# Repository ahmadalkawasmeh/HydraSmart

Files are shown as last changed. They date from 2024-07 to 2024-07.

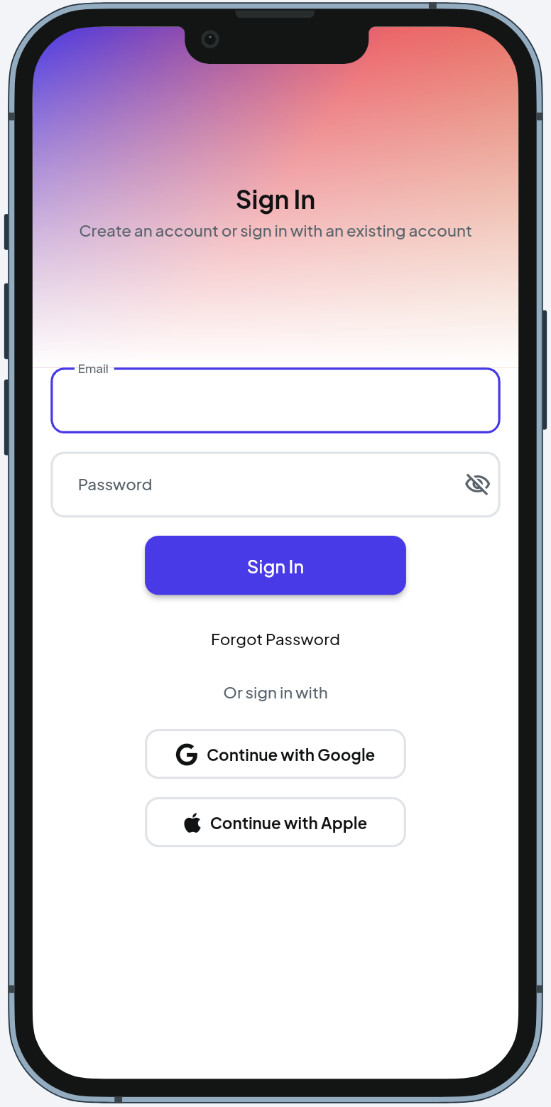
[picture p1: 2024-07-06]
application preview/loginPage.png

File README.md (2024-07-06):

## About
The focus of this project was to implement a portable and smart drinking water quality monitoring system,
in order to address the lack of availability of such product and the disadvantages of using conventional
paper test strips to measure water quality. The developed system consists of multiple sensors that infer
useful measurements about the water quality, conveniently built into a water bottle, as well as a mobile
application that provides an intuitive user interface for the user to interact with the system. This enabled
the users to be confident in the quality of water they intend to consume, without compromising
convenience or ease of use.

## Features
- Measures water quality in real time
- Sensors and other hardware components built into a water bottle for convenience
- Precisely calibrated and thoroughly tested for high accuracy
- Utilizes a rechargable battery for portability
- Simple and intuitive user interface design
- Compatible with both Android and IOS devices
- User data is encrypted and securely stored

## Key Documents
- [Final Report](https://github.com/ahmadalkawasmeh/HydraSmart/blob/main/documents/Final%20Report.pdf)
- [Application Screenshots](https://github.com/ahmadalkawasmeh/HydraSmart/tree/main/application%20preview)
- [Engineering Technical Drawings](https://github.com/ahmadalkawasmeh/HydraSmart/blob/main/documents/Engineering%20Technical%20Drawings.pdf)

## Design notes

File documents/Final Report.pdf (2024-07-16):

# ECOR 4907

# Capstone Project

# HydraSmart Final Report

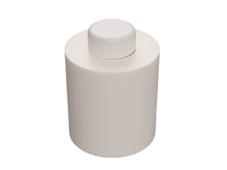
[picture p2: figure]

Prepared for:

Professor Safaa Bedawi

Professor Lynn Marshall

By:

Abdal Alkawasmeh, 1011987252

Ahmad Alkawasmeh, 101108706

July 10, 2024

FINAL REPORT

# Abstract

Have you ever thought about the cleanliness of your drinking water? Do you have to constantly drink

bottled water? Are you tired of second guessing if you should drink tap water? water quality has become

an emerging issue over the years and water quality systems have become more in demand.

In this project, we implement an automated water quality system which allow users to test the quality of

a water sample. Using a few metrics, the system provides the user with water quality readings and

determine the drinking water's safety by displaying a message to the user. By using this product, the user

will be able to carry and sample any water from anywhere.

This product ensures that the user consumes safe and drinking water and has many applications to its

users. However, it is most beneficial for those travelling or who do not have access to filtered water. For

example, teachers may wish to check the water quality on a field trip before the children start to consume

it.

# Acknowledgements

Special thanks to Professor Bedawi and Professor Marshall for their continued support and dedication. It

has been a pleasant and an amazing experience working with you. Although this project is coming to an

end, you have left us with an everlasting experience that reinforced professional practice and discipline

throughout the duration of the project. This has not only been instrumental to our success in this project

but will also be a major factor in our success throughout our careers.

We would also like to acknowledge Professor Dansereau and thank him for the valuable feedback he

provided us with.

Sincerely,

Ahmad and Abdal Alkawasmeh

## Table of Contents

## 1 Introduction

### 1.1 Background

We go about our everyday lives without giving much thought to the quality of water that we consume

daily. Especially as we need to consume a substantial amount of water daily, which is approximately 3.7

litres, to maintain healthy body functions. Thus, it is important to pay close attention to the quality of the

water we consume on a daily basis.

Currently, the most widely used technique of determining water quality is by using test strips, which are

rectangular pieces of paper that are saturated with a chemical agent, once these paper strips are

submerged in a water sample, the chemical agent will react with the water and change colour. This colour

indicates the test result, which then the user will need to match to a result chart in order to read the test

result. This method of testing the water quality is not accurate and cannot provide exact quantitative

results.

Another downside to using the test strips pertains to users with a visual impairment. Due to the inherent

nature of the test strips relying on a colour change to convey the test results, users with visual

impairments related to colour blindness may face difficulties using the test strips.

### 1.2 Motivation

The goal of this project was to develop a more suitable solution for monitoring the quality of drinking

water and to address the downsides of using traditional test strips.

For users with visual impairments, it can be challenging for them to discern fine differences in shades of

a certain colour. Which is the mechanism that test strips rely on to convey the test results to the user.

Thisinherently introduces a barrier for this group of users, and this method of evaluating the water quality

may even become unusable for them.

During our research into the existing solutions for monitoring drinking water quality, it became apparent

that there are currently no solutions for evaluating the quality of drinking water that are portable,

convenient, and simple to use by the end user. This creates a high demand for such a solution as it has a

wide range of applications and use cases.

For parents, it would put their minds at ease after becoming aware of the water quality their children will

consume, especially during times of uncertainty, such as when travelling or visiting a new city where they

are not sure of how that specific municipality treats their water.

For teachers, if they are accompanying children on a field trip, it would be immensely helpful to be able

to check the water quality before everyone consumes it. Moreover, if the water happens to be acidic or

contains contaminants, it will not provide the necessary hydration at the least, and in the worst-case

scenario it would cause everyone to get sick. Thus, a simple test prior to consumption would allow us to

mitigate any risks of consuming water that is of unknown quality or content.

### 1.3 Problem Statement

There are many drawbacks to using traditional test strips for assessing drinking water quality. The test

strips have a low accuracy for the test results asthe result is conveyed to the user through a colour change.

Aside from the lack of a quantitative test result, the colour change mechanism in itself can become

problematic for some users. Moreover, users with visual impairments may not be able to use the test

strips as they require acute colour perception to evaluate the test results. Additionally, there is a lack of a

suitable solution for assessing the quality of drinking water conveniently by the end users. Therefore, it is

essential to develop a product that addresses the disadvantages of traditional water quality testing

mechanisms and provides a solution to the public for evaluating the quality of drinking water

conveniently.

### 1.4 Proposed Solution

The solution proposed is a complete system (referred to as HydraSmart) for monitoring the quality of

drinking water. HydraSmart comprises multiple sensors conveniently built into a water bottle and a mobile

application that acts as an interface between the user and HydraSmart. This proposed solution is

convenient to use, portable, and provides highly accurate results. Thus, eliminating the disadvantages of

traditional mechanisms for evaluating the quality of drinking water, while simultaneously addressing the

lack of such a solution for the general public.

### 1.5 Overview Of Remainder of Report

This report describes the research, design and implementation process of the HydraSmart system. The

introduction introduces the team members, the objectives of this system, background and motivation,

problem statements and the proposed solution. This gives the reader a thorough understanding and

importance of the overall project.

The Engineering project discusses the health and safety concerns of the system, the professionalism,

describes the management process, the justification for choosing the project and the contributions of

each member. The Background section focuses on the background of the front end and backend, and the

hardware components. The requirements section describes the functional and non-functional

requirements of the system. The design section describes the design process of the front-end, back-end

and the physical water bottle design. The implementation sections describe the detailed implementation

process of the system, discussing the Figma mock-ups, the back-end implementation of the mobile app,

and the water bottle implementation of wiring, 3D-model and sensor integration. The theory and

techniques discuss the justification of the components in the system. Results and discussion show the

results of the system we were able to obtain and discuss future improvements.

## 2 The Engineering Project

### 2.1 Health and Safety

The system is designed to ensure the health and safety of the user in order to ensure a safe and positive

user experience. The design incorporates three hazardous components, electrical equipment, a

rechargeable battery, and glassware. These components are capable of causing bodily harm to the end

user if the product is mishandled or misused. However, health risks can be mitigated with appropriate

precautions and safety-centred design.

Due to the utilization of electronics and electrical components in this project, there is a risk of electrical

shock to the end user if the device is misused. Section 6.4 of the Health and Safety Guide outlines the

concept of guarding to prevent access to electrical components. Subsequently, the electrical connections

and components were placed in a waterproof compartment that is inaccessible to the user. Moreover,

the user will not be able to make contact with the wiring and electrical components of the system, thus

mitigating the risk of an electrical shock.

One of the system components will be a rechargeable battery pack, which was used to supply power to

the system and allow it to be mobile. The battery pack type is Lithium-Ion, which remains in a stable state

so long the battery casing is intact. If the casing becomes punctured or compromised at any time, the

battery may catch on fire. This would be catastrophic as it can cause severe burns to the user. As per

section 6.6 of the Health and Safety Guide, the use of Shielding is recommended for materials or chemicals

that may cause explosions and fires. As such, the strategy to mitigate this risk was to encase the battery

pack in metallic plates. This will reinforce the original plastic casing making it significantly harder to

penetrate.

Two sensor probes are made of glass and could pose a health risk if they break. As per section 6.7 of the

Health and Safety Guide, broken glassware should be handled and disposed of safely. Moreover, protective gloves and eyewear should be used when handling broken glass to minimize the risk of cuts. If

a sensor probe breaks, the recommended disposal method is to carefully place the broken glass in a

cardboard box, taping the box shut, labelling the box with "Broken Glass", and placing it next to the

garbage bin. This will minimize the risks and ensure it is handled safely by anyone that comes into contact

with it. Additionally, it is recommended to apply a thick layer of tape to the exterior of glassware to

prevent it from dispersing when broken. This was applied in the final product to minimize the health risks

to the end user.

### 2.2 Engineering Professionalism

One component of the 4th year engineering project is to demonstrate how our professional responsibilities

were met throughout the performance of the project. Previously, we completed a professional practice

course, ECOR 4995. Although it placed a strong emphasis on communication skills, it also taught us about

professional responsibilities, health and safety, and principles of sustainable development.

Throughout the duration of our project, we continuously utilized the concepts we were taught in

professional practice to communicate, amongst the team and with our supervisors, in an effective and

professional manner. To achieve this, we ensured our written communication is kept concise and

accurate.

Additionally, during our meetings and discussions, we made sure to always be punctual and be present

prior to the meeting time. This helps us conduct ourselves in a professional manner and demonstrates

that we highly value our supervisors’ time. However, on one occasion, we experienced unforeseen

circumstances that prevented us from attending the meeting on time. We immediately informed our

supervisors of this and provided an estimated arrival time, as it otherwise would be inappropriate.

The most notable component of professional practice that pertains to the goals of this project is

sustainable development. Sustainable development is concerned with preserving the environment and natural resources, in order to avoid impacting future generations' ability to make use of such resources.

HydraSmart will help reduce the amount of plastic waste resulting from disposable water bottles, thus

helping to preserve the environment from pollution and non-organic waste.

Another aspect of professional practice is health and safety and safeguarding the public. The concept of

public safeguarding pertains to making decisions that prioritize public safety. Throughout this project

development, public safety was considered the fundamental concept and main motivation. HydraSmart

will help upkeep the public safety and health by ensuring the water is fit for consumption, thus reducing

the chance of facing experiencing issues caused by drinking water that was not fit for consumption.

### 2.3 Project Management

We greatly benefited from creating a Gantt chart [Appendix C: Project Progression Gantt Chart] early on

to schedule and organize the execution of the project tasks throughout the duration of the project. This

helped us carry out the project objectives in an effective and efficient manner. Evidently, we employed

the principles of the Waterfall lifecycle model throughout the duration of this project, where we

incrementally completed each part before moving on to the next part. This ensured there are no broken

dependencies across the different parts of the projects, therefore increasing our efficiency.

We used JetBrains’ YouTrack in order to track our progress and identify any issues that must be resolved

in order to continue progressing through the project. YouTrack has a Gantt chart tool conveniently built

in, seamlessly enabling task allocation and progress tracking.

### 2.4 Justification of Suitability for Degree Program

The team members consist of Software Engineering students with a parallel experience in software

development, however, each member has a unique interest and background experience.

Ahmad employed his previous knowledge about software architecture and design from SYSC 4120 to

outline and analyze the system requirements. The knowledge acquired from COMP 3004 allowed him to

design the persistence layer of the mobile application. Utilizing Nielson’s Heuristics from SYSC 4130

enabled him to design an intuitive and user-friendly interface for the mobile application. His knowledge

in software verification and validation from SYSC 4101 assisted him in verifying correct sensor behavior.

The knowledge in design and analysis of automatic control systemsfrom SYSC 4505 allowed him to analyze

the sensor response characteristics. Additionally, the Introduction to Engineering (ECOR 1010) course

allowed him to acquire the necessary expertise in prototyping and 3D design, which was greatly utilized

in this project to design a custom water bottle housing.

Abdal’s interest is purely vested in software development. More precisely in user interface design and

identifying system requirements. He has taken on multiple personal projects in the past involving website

design and development, and he has an extensive experience in working with distributed database

systems. Some examples of related work include a sandwich ordering system web user interface which

was implemented in SYSC 3010. He has also used his knowledge in SYSC 4101 software verification and

validation to use various software testing strategies to verify that the sensors and IDE were operating

correctly. Also, the software architecture and design, SYSC 4120, helped him in identifying the functional

and non-functional requirements of the system.

Therefore, it is evident the expertise and experience required to complete this project has been greatly

reinforced by the undergraduate Software Engineering program. Thus, making this project a perfect fit for

Software Engineering students.

### 2.5 Individual Contributions

Please note that due to the limited number of team members in this project, each member contributed

to all the tasks outlined below and they are only categorized by each person based on the member that

contributed to completing more than 50% of the mentioned task.

2.5.1 Project contributions

Abdal | Ahmad
Software testing | Hardware component testing
Development of the mobile application | Development of the mobile application
Integration of pH, TDS and turbidity sensors | Integration of EC, and Temperature sensors
Calibration of sensors | Back-end Testing
Front-end Design | Back-end Design
Back-end Design | Interfacing portable battery power supply into the Raspberry Pi
Hardware Design | Hardware Design

Table 1: Breakdown of Project Contributions of Each Member

2.5.2 Report contributions
Abdal | Ahmad
Chapter 2: Engineering Design | Chapter 1: Introduction
Chapter 5: Hardware Required | Chapter 3: Work Plan
Chapter 6: References | Chapter 4: Project Risks and Mitigation Strategies
| Appendences

Table 2: Breakdown of Proposal Contributions of Each Member

Abdal | Ahmad
Abstract | Chapter 2: Professional considerations
Chapter 1: Introduction | Chapters 3.2 and 3.3: Design Functionality Verification, Experiment Design and Setup
Chapter 2.1: Health and safety | Chapter 4: Results and Discussions
Chapters 3.1 and 3.4: Generation of Alternative Design and Assessments, Hardware and Software Tools | Chapter 5: Conclusion

Table 3: Breakdown of Progress Report Contributions of Each Member

Abdal | Ahmad
1: Introduction | 2.0: The Engineering Report
2.4: Justification of Suitability for Degree Program | 3.1.1: FlutterFlow 3.1.2: Firebase
3.1.3: Background: Fusion 360 3.1.4: Background: Arduino IDE 3.2: Hardware | 5.1: Frontend Design 5.2: Backend Design
4: Requirements | 7.1: Frontend Implementation 7.2.1: Firebase-Application Line 7.2.2: Firebase Data Query and Update 7.2.3: Data Processing
5.3: Hardware Design | 8.2: Hardware Testing
6.1-6.6: Alternative Solutions Analysis | 9.0: Project Milestones
7.2.4-7.2.6: Hardware Implementation | 10.0: Conclusions
8.1: Software Testing | References and Appendences

Table 4: Breakdown of Final Report Contributions of Each Member

## 3 Background

### 3.1 Software

3.1.1 FlutterFlow

FlutterFlow was chosen for our mobile application development platform, see Chapter 6 for the trade-off

analysis of all our technologies and tools discussions.

FlutterFlow is a complete application development platform which houses all the necessary tools to

develop a mobile application from the ground up. It utilizes the Flutter Software Development Kit (SDK)

framework alongside the Dart programming language to develop high-quality mobile applications.

The Flutter SDK is universally compatible with Android and IOS devices, as well as multiple programming

languages such as Java, C, and Swift. This provides ultimate flexibility enabling application deployment to

multiple operating systems simultaneously.

Dart is a modern object-oriented programming language created by Google. This makes it seamless to

integrate other solutions created by Google into the mobile application, such as the Firebase data

persistence solution by Google. An added advantage of using FlutterFlow, is the ability to compile the Dart

application into JavaScript, enabling live testing and editing in a browser window.

While the graphical interface of the mobile application is developed using Dart and Flutter, it is formatted

in eXtensible Markup Language (XML), which is a popular format amongst graphical user interface

developers. It is known for its flexibility and universal compatibility with a wide range of operating systems

and programming languages.

Additionally, FlutterFlow makes it possible to develop for both Android and IOS devices simultaneously.

This is enabled through the Flutter Software Development Kit (SDK).

3.1.2 Firebase

To synchronize and store the sensor measurements, we used Firebase. Which is a data storage solution

created by Google. Similarly to Dart, Google provides exceptional and seamless integration between its

products. This made Firebase the clear choice when deciding on a database solution.

Firebase is a real-time database, meaning data updates are reflected immediately within the database.

This is a highly valued feature in applications that rely on live data to achieve a specific functionality. In

our project, it is imperative that the mobile application is able to retrieve live data from the sensors to the

user.

3.1.3 Arduino IDE

The main IDE we used to integrate the sensors into the system was Arduino. Arduino is a software

application built on C++. It provides users with a user-friendly interface that is easy to navigate and

develop code with. It also comes with many built in libraries allowing for advanced functionalities such as

sensor readings. It is also important to note the open-source feature, meaning that users can modify code

according to their needs or their specific application.

3.1.4 Fusion 360

To Design the 3-D model of the water bottle, we used fusion 360, a 3-D computer aided design program

created by Autodesk. This software is well known for its affordability, flexibility and many use of

applications. It’s also compatible with many operating systems such as MacOS, windows, and Sonoma.

It also has many functionalities such as generative design, rendering, and simulation. The generative

design uses an existing model structure and improves it by reducing the materials while attempting to

improve shear and normal resistance. This software is also equipped with fast rendering abilities allowing

the visualization of any 3D models. Fusion also uses finite element analysis which evaluates the mechanical properties of an object. This feature is quite critical in decision making between different

material manufacturing types, ensuring the best durability of the designed product [1]

### 3.2 Hardware

3.2.1 Temperature Sensor

The temperature sensor was a crucial part of our system. It helps provide accurate measurements of

other sensors as temperature is part of the formula used to calculate the readings. For example, when

temperature increases in a solution, the equilibrium is forced to lower the temperature by absorbing

more heat. This results in more formation of H+ ions and therefore a lower pH of a solution [2]

Similarly, with electrical conductivity, as the temperature of the water increases, the electrical

conductivity also increases. At higher temperatures, water molecules move more quickly, carrying more

charged ions. Therefore, this increases the overall conductivity [3].

3.2.2 EC Sensor

The electrical conductivity sensor determines the concentration of ions/dissolved substances in a

solution, where high conductivity usually means a higher amount of salts present in the solution and

vice versa [4]

This measurement is used in many applications such as cooling towers and wastewater management,

and each measurement in an application could mean various things. Even small amounts of salts can

result in high conductivity. It’s also possible that the water could be polluted or an existence of a sewage

leak. An EC sensor is made up of two surfaces, platinum and graphite, and a voltage waveform is sent

from one surface to the other, providing an EC reading [5]

3.2.3 pH Sensor

The pH sensor is used to determine the alkalinity of water in our system, a very important measure in

water quality. This measurement is used in a wide variety of applications such as swimming pools and

aquaculture. It’s important to understand that a pH value that is too low or too high could determine

the presence of heavy metals, or other toxic materials [6]. Most fish and aquatic animals have a pH

threshold of 6.5-9, so most aquatic systems add buffers to prevent pH fluctuations. In swimming pools,

pH of water is usually kept at 7.2-7.8, and if a pH rises too much, this can result in growth of algae and

bacteria. Drinking water should have a pH of 6.5-8.5 for safe human consumption. When the pH is too

acidic, it can damage pipes and can cause metal built up. When the pH is too basic, it can cause a change

in taste of water [8].

3.2.4 Turbidity Sensor

A Turbidity sensor measures the transparency or clearness of water. A high level of turbidity can indicate

sediments or pollutants in water [9]. This measurement is very commonly used in water treatment to

determine if water has been treated successfully [10] Turbidity is measured in NTU or FTU, where in

developed countries drinking water should be kept under 1 NTU and 5 NTU in developing countries. It’s

also helpful in determining the number of pollutants in water in the case of financial and technical

limitations [11].

A Turbidity sensor measures the transparency or clearness of water. A high level of turbidity can indicate

sediments or pollutants in water [9]. This measurement is very commonly used in water treatment to

determine if water has been treated successfully [10] Turbidity is measured in NTU or FTU, where in

developed countries drinking water should be kept under 1 NTU and 5 NTU in developing countries. It’s

also helpful in determining the number of pollutants in water in the case of financial and technical

limitations [11].

3.2.5 TDS Sensor

A TDS sensor measures the total dissolved solids, more specifically, the amount of minerals in water.

There are many sources of dissolved solids such as minerals, agritictural runoff and industrial pollution.

While some dissolved solids are beneficial, high TDS values can be harmful. Minerals such as calcium and

magnesium are usually present in water and are beneficial for human health. However, high levels of

TDS can cause health problems those with certain conditions such as high blood pressure, or kidney

disease. TDS is calculated by measuring the electrical conductivity of water and converting it to a TDS

reading. The amount of conductivity indicates the number of ions in the water, therefore providing a

TDS reading. The unit of measurement used to measure the TDS of a solution is ppm (parts per million),

indicates the concertation of one part in a million. The world health organization (WHO) recommends a

TDS level of less than 500 ppm for drinking water, but this can vary depending on the source and desired

use. For an example water used for plants can have a higher TDS [12].

A TDS sensor measures the total dissolved solids, more specifically, the amount of minerals in water. There

are many sources of dissolved solids such as minerals, agritictural runoff and industrial pollution. While

some dissolved solids are beneficial, high TDS values can be harmful. Minerals such as calcium and

magnesium are usually present in water and are beneficial for human health. However, high levels of TDS

can cause health problems those with certain conditions such as high blood pressure, or kidney disease.

TDS is calculated by measuring the electrical conductivity of water and converting it to a TDS reading. The

amount of conductivity indicates the number of ions in the water, therefore providing a TDS reading. The

unit of measurement used to measure the TDS of a solution is ppm (parts per million), indicates the

concertation of one part in a million. The world health organization (WHO) recommends a TDS level of

less than 500 ppm for drinking water, but this can vary depending on the source and desired use. For an

example water used for plants can have a higher TDS [12].

3.2.6 Arduino Uno R4 Microprocessor

An Arduino Uno R4 Wi-Fi is a microcontroller used to integrate the sensors, and other hardware. It

combines the processing power of the RA4M1 microcontroller from Renesas with the wireless

connectivity power of the ESP32-S3 from Espressif. The UNO R4 Wi-Fi has an expanded memory of 32 kB

and clock speed of 48 MHz, enabling precises calculations [13].The 12-bit Digital to analog converter

provides simplicity, and compatibility to most hardware. This microcontroller is also equipped with Wi-Fi

and Bluetooth built in the ESP32-D3 module, enabling users to connect wirelessly. In addition, this board

is equipped with a 24 V tolerance allowing for more hardware integration using a single power source. As

an error detection mechanism, this board is able to detect runtime errors and provides detailed

explanations about the error [14].An Arduino Uno R4 Wi-Fi is a microcontroller used to integrate the

sensors, and other hardware. It combines the processing power of the RA4M1 microcontroller from

Renesas with the wireless connectivity power of the ESP32-S3 from Espressif. The UNO R4 Wi-Fi has an

expanded memory of 32 kB and clock speed of 48 MHz, enabling precises calculations [13].The 12-bit

Digital to analog converter provides simplicity, and compatibility to most hardware. This microcontroller

is also equipped with Wi-Fi and Bluetooth built in the ESP32-D3 module, enabling users to connect

wirelessly. In addition, this board is equipped with a 24 V tolerance allowing for more hardware

integration using a single power source. As an error detection mechanism, this board is able to detect

runtime errors and provides detailed explanations about the error [14].

## 4 Requirements

Our system has two main components, the mobile application and the hardware. The mobile application

serves as a user interface while the hardware is responsible for the functionality of the sensors. Therefore,

by combining the two components, we developed a portable drinking water quality monitoring system,

ensuring the ease of use and convenience.

The system requirements are portioned into functional and non-functional requirements. The functional

requirements specify and describe the behaviour of the system, while the non-functional requirements

specify how the system should perform.

Functional requirements:

- The system shall be able to measure the pH level of the water with an accuracy of ± 0.1 in a range

of 0-14.

- The system shall be able to measure the amount of Total Dissolved Solids (TDS) in the water with

an accuracy of ±10 ppm within a range of 0-1000 ppm.

- The system shall be able to measure the amount of Total Suspended Solids (TSS or Turbidity) in

the water with an accuracy of ±10 NTU within a range of 0-1000 NTU

- The system shall be able to measure the Electrical Conductivity (EC) of the water with an accuracy

of ±100 µS/cm within a range of 0-10,000 µS/cm

- The system shall be able to measure the Temperature of the water with an accuracy of ±1 °C

within a range of 0-100 °C.

- The system shall have a graphical user interface which displays the readings of pH, TDS, TSS, EC.

Non-functional requirements:

- The user interface shall be friendly and intuitive to use.

- The system shall be compatible with both iOS and Android devices.
- The system hardware component shall be placed in waterproof and drop proof enclosure.
- The system shall support only 2.4 GHz Wi-Fi connection for maximum compatibility.
- The mobile application shall allow users to sign in using multiple methods for convenience.
- The system shall ensure the data is stored safely by preventing an unauthorized party from

accessing the data.

- The system shall prompt the users to sign in before allowing them to navigate the mobile

application.

- The mobile application shall update the displayed data within 10 seconds of being fetched.

## 5 Design

### 5.1 Frontend Design

The frontend design started by creating preliminary user interface mock-upsin Figma. During this process,

the goal was to design the mobile application pages in a simplified and high-level fashion. By creating the

mock-ups, it streamlined the implementation later in Flutter.

We designed a set of pages for the mobile application user interface. These pages [Appendix A: Mobile

Application Screens] were designed as follows:

- Welcome page: a landing page that appears upon launching the application to welcome the user

and it contains a single button to proceed

- Login page: the page where a user can create an account or sign in
- Home page: provides an overview of the recent measurements plotted on a graph. It also contains

two buttons named “Settings” and “Analytics Dashboard”

- Settings page: this is where the user can view and edit their profile, log out, and switch between

a dark and a light interface. It also contains a go-back button to navigate back to the home screen.

- Analytics dashboard page: this page displays a summary about the sensor measurements, and it

refreshes every 2 minutes automatically. It displays a button named “Measure” the user can press

and take an immediate measurement manually. Additionally, pressing on any of the sensor names

will navigate to a page that is dedicated to that specific sensor. In the upper left corner, there is a

“go-back” button to navigate back to the home screen.

- pH, EC, TDS, and Turbidity pages: each of these pages contain the same elements, the sensor

measurement and its units, a short explanation of what the measurement entails, ideal

measurement value, and a “go-back” button to navigate back to the dashboard page.

- E. coli page: this page displays the levels of E. coli bacteria present in the water of the beaches

and rivers in Ottawa, which are provided daily by the City of Ottawa.

Additionally, we utilized the principles of usability we learned about in our Human-Computer Interaction

course we completed previously. These principles, such as Nielsen’s Heuristics, can be used as a general

guideline during the design of user interfaces to increase usability, make the interface more intuitive to

use, and minimize issues users may face while using the application.

The first principle we applied is referred to as “Recognition Rather than Recall”. This principle is the most

widely applied across user interfaces. It is concerned with minimizing user memory load by enabling them

to recognize an action they need to perform in order to complete a certain task. For example, in

smartphones, the gear icon on the home screen allows the user to recognize that it refers to the Settings

page without having to recall that. This introduces a sense of familiarity within the interface and allows

the user to navigate it seamlessly.

In our case, there is two buttons on the home screen of the mobile application, “Settings” and “Analytics

Dashboard”. We used a gear icon for the “Settings” button, and a trendline icon for the “Analytics

Dashboard” button.

The second principle we applied is referred to as “User Control and Freedom”. This principle is concerned

with providing the user with complete freedom in navigating the interface as they please. Additionally, it

includes the ability to go back or undo an action the user performed previously. This makes the user more

comfortable with navigating the interface and be confident to explore the interface without hesitation.

Throughout the application pages, we ensured to include a go-back button on every page, providing

complete freedom to the user in navigating the application pages. We also used a left-arrow icon for this

button, repeatedly applying the “Recognition Rather than Recall” principle.

The third principle we applied is referred to as “Aesthetic and Minimalist Design”. This principle is about

excluding irrelevant and rarely used information from being displayed on an interface. Otherwise, the

extra information displayed on an interface competes with the relevant information and diminishes their

relative visibility. Throughout the application interface, we ensured that each page displays only the

essential information only. For example, the dashboard page displays ratings of sensor measurements

initially, and instructs the user to press on a sensor name to view more information about it. Once the

user presses on a sensor name, a secondary page is shown, and it displays detailed information dedicated

to that sensor.

This is also related to Fitt’s Law predictive model, which states that the time to point to an object is a

function of the distance from target object and the size of that object. In other words, the user will be

able to point to a larger sized object faster than a smaller sized object. Moreover, the more elements

displayed on an interface page, the less attention the user is going to assign to each of these elements.

Therefore, it is more preferrable to partition information and elements amongst multiple pages rather

than having one large page, effectively enabling the user to pay adequate attention to each page or set of

elements.

### 5.2 Backend Design

We started the backend design process by designing a Firebase database schema to account for the data

and measurements we need to persist throughout the system. The database needed to include four

tables.

The first table, named “users”, was needed to store the profile information of the users. Including user id,

photo, name, and email. This information is needed by the application in order to create a new user and

authorize them to use the application.

The second table, named “sensorData”, was needed for storing and retrieving sensor measurements. It

contains 4 rows that store the measurements of the pH, Electrical Conductivity, Turbidity, and Total

Dissolved Solids sensors.

The third table, named “liveMeasure”, was needed to facilitate the communication between the mobile

application and the Arduino microprocessor. It contains one row that stores a single integer, either a 1 or

0.

The fourth table, named “eColi”, was needed to relay the current levels of E. coli bacteria present in

beaches and rivers in Ottawa, and whether there has been rainfall in the past 24 hours. The table contains

4 rows that store the E. coli levels, and one row that stores the rainfall status for the previous 24 hours.

Additionally, we wanted to ensure that the database and the stored data is kept safe. There are two critical

categories of data that are of concern. The first is the Firebase API access key, which is used to update and

query data from the database, is stored by the mobile application and the Arduino microprocessor. This

key was encrypted using SHA-256 and can only be decrypted by the mobile application and the Arduino

at runtime. The second critical data category was the actual data stored within the Firebase tables, this

data was encrypted using SHA-1 and similarly to the API access key, it can only be decrypted at runtime.

The sensors are controlled using two Arduino scripts. The first script contains several libraries to function

the sensors. Another script was included to contain the credentials of the firebase project and Wi-Fi

network. Once the sensor script is run, it automatically connects to the specified network and all sensor

data is printed in the serial monitor. This data is also sent to the firebase in real-time which is then shown

in the mobile application.

### 5.3 Hardware Design

The physical design of the water bottle is designed using fusion 360, which consists of three main

components, the inner cylinder, the outer cylinder and grommet seals. The inner cylinder’s purpose is to

fit the sensors. The outer cylinder’s purpose is a platform to hold the sensors. The grommets are to ensure

proper fitment of each sensor. To ensure the measurements was accurate, we carefully and iteratively

measured each sensor’s dimensions using calipers. Then, different mounts were designed for each sensor

on the bottom of the water bottle ensuring stability of the sensors and accessibility to water. We also took

into consideration the dimensions of the breadboard, rechargeable battery and the Arduino board as they

are required to power the sensors. The turbidity sensor is short in length, and therefore was placed on

the lowermost front position on the inner cylinder. A complete list of the hardware components we used

can be found in [Appendix D: List of Hardware Components Used]. Additionally, the detailed datasheet

for each component can be found in [Appendix E: Hardware Components Datasheets].

## 6 Generation and Analysis of Alternative Solutions

### 6.1 Microprocessor

When choosing a microprocessor for the system, we considered two options: the Arduino uno and the

Raspberry Pi. The Arduino Uno supports both analog and digital inputs, making it compatible with various

sensors. It’s simpler to program, ideal for development. Additionally, it is more energy efficient making it

suitable applications equipped with batteries. However, the Arduino Uno lacks an operating system, which

limits the potential of complex projects, and is more suitable for simpler ones [15].

The Raspberry Pi offers compatibility for digital input and runs a full operating system, providing complex

abilities and software support. It’s better suited for projects requiring more complexity. However, this

option is more expensive, lacks compatibility for analog input and consumes more power.

Due to our system requirements, the Arduino was found to be more feasible. Our sensors requiring both

analog and digital inputs, and the Arduino’s lower power consumption played important factors in this

decision. Although the Raspberry Pi offered more flexibility, it’s higher cost and power usage made it less

suitable for our needs [16].

Microprocessor/microcontroller | Advantages | Disadvantages
Arduino Uno R4 Wi-fi | • Includes analog and digital pins • Simple and easy to use • Low power consumption | • Does not use an operating system • Suitable for only small applications • 8-bit CPU architecture
Raspberry Pi | • Has 40 digital pins | • Does not support analog input

- Suitable for large and

complex applications

- Runs on an operating

system

- More expensive
- | High | power
| consumption

Table 5: Trade-off Analysis of Microprocessor/Microcontroller

### 6.2 Temperature sensor

When choosing a temperature sensor, there were several options available. However, the two most

competitive were the DFRobot DS18B20 and DFRobot TMP100. The DS18B20 model has it’s benefits like

being waterproof, smaller in size, and a more affordable option. However, it has a slightly less accuracy,

measures up to 125 and takes a few minutes to stabilize [17] [18]. The TMP100 model, on the other hand,

offers higher accuracy, stabilizes very quickly, and is compatible with both 5V and 3.3V systems, including

the Arduino DUO and UNO models. Given our goal to keep costs low, and the need to measure

temperatures of water solutions, we chose the DS18B20 model [19] [20].

Sensor | Advantages | Disadvantages
DFRobot DS18B20 | • Waterproof • Compact size • Affordable | • Less accurate • Measures temperature only up to 125 • Takes time to stabilize
DFRobot TMP100 | • High accuracy • Quick stabilization • Compatible with 5V and 3.3V | • Not waterproof • More expensive • Requires soldering

Table 6: Trade-off Analysis of Temperature Sensor

### 6.3 pH sensor

To choose the optimal pH sensor, we evaluated two popular options: the DFRobot model and the Grove

model. The DFRobot model can measure a wider temperature range, from 0 to 60, while the Grove

model is limited to 55. Additionally, the DFRobot model has a faster response rate of 1 minute and

includes a power LED indicator [21].

The Grove model offers several benefits, such as a smaller probe size, higher accuracy rate, and the

convenience of requiring calibration only once [22] . However, it has a slower response rate of more

than a minute, shorter probe life of 6 months and a longer cable length, which is not optimal for

minimizing materials [23] [24]

Despite the Grove model’s higher accuracy and smaller probe size, the DFRobot offers a wide temerpature

range, and a faster response rate. Therefore, given our needs and requirements, the DFRobot pH meter

was found more suitable.

Sensor | Advantages | Disadvantages
DFRobot pH meter | • Measures a wider temperature range • Faster response time • Includes power LED indicator | • Less accurate • Larger probe size • Requires frequent calibration
Grove pH sensor | • Smaller probe size • Higher accuracy • Only requires one-time calibration | • Slower response time • Shorter probe lifespan • Longer cable length

Table 7: Trade-off Analysis of pH Sensor

### 6.4 TDS sensor

When deciding on the TDS sensor, we compared two competitive products: the DFRobot Gravity TDS

sensor and Grove TDS sensor. The DFRobot sensor has a lower error rate, is waterproof, and can operate

with both 3.3V and 5V of power. However, it has a larger wire size, is only compatible with Arduino and

requires frequent recalibration [25]. In contrast, the Grove sensor has a shorter wire length, does not

require recalibration and is compatible with both Raspberry Pi and Arduino, however it has its limitations

such as not being useable in polluted water, not functioning in temperatures over 70, and lacking

waterproof capabilities [26].

Given our comparison, the DFRobot Gravity TDS sensor was found to be more suitable for our system.

Despite it’s larger wire size and need for frequent calibration, it’s waterproof capabilities and lower error

rate makes it the more optimal choice for our needs.

Sensor | Advantages | Disadvantages
DFRobot Gravity TDS analog sensor | • High accuracy • Waterproof probe • Compatible with 3.3V and 5V | • Longer wire size • Not compatible with Raspberry pi • Requires frequent calibration
Grove TDS sensor | • Shorter wire size • No recalibration required • Compatible with the Raspberry Pi and Arduino | • Not suitable for water temperatures over 70 • Cannot be used in polluted water • Non-waterproof probe

Table 8: Trade-off Analysis of TDS sensor

### 6.5 Turbidity sensor

When choosing a turbidity sensor, we considered two options: the DFRobot and the Grove sensor. The

DFRobot model is lighter in weight, more affordable, and has the ability to adjust the threshold. However,

it has its limitations, such as only being compatible with the Arduino, a slower response rate and requiring

calibration [27]. The Grove sensor is more beneficial in terms of power consumption, size, and output

support. However, it is more expensive, slightly heavier, and requires calibration [28].

Despite the slower response time, and requiring calibration, the DFRobot model offers significant

advantage in cost and weight. Therefore, based on our analysis, it was found to be a more practical option

for our project.

Sensor | Advantages | Disadvantages
DFRobot Gravity Turbidity sensor | • Lighter weight • More affordable • Adjustable threshold | • Only compatible with Arduino • Slower response time • Requires calibration
Grove Turbidity sensor | • Less power consumption • Smaller size • Supports both digital and analog output | • More expensive • Slightly heavier • Requires calibration

Table 9: Trade-off Analysis of Turbidity Sensor

### 6.6 EC sensor

When evaluating the DFRobot Gravity EC sensor and the Grove EC sensor, several factors were considered

including probe life, temperature range, compatibility, cost, and power consumption.

The DFRobot Gravity EC sensor offers a longer probe life, making it suitable for extended use and is also

more cost-effective. Also, it has a greater EC detection range which provides more application flexibility.

However, it has it’s limitations such as operating in a smaller temperature range, and consumes more

power [29]. The Grove EC sensor has the ability to operate in a larger temperature range, providing more

flexibility. It’s also compatible with both the Arduino and Raspberry Pi. Additionally, it consumes less

power. However, some limitations include a higher cost, a shorter probe life, and a low electrical

conductivity detection range [30].

Since cost and an EC detection range are very important to this project, and we are exclusively working

with the Arduino, the DFRobot is a more suitable choice.

Sensor | Advantages | Disadvantages
DFRobot Gravity EC sensor | • Longer probe life • Cost-effective • Greater EC detection range | • Narrower temperature range • Only compatible with Arduino • Higher power consumption
Grove EC sensor | • Wider temperature range • Compatible with Arduino and Raspberry Pi • Lower power consumption | • More expensive • Shorter probe life • Lower EC detection range

Table 10: Trade-off Analysis of EC Sensor

### 6.7 Software

6.7.1 Mobile Application Platform
For choosing a mobile application development platform, Flutter and React Native were evaluated on

several factors such as performance, useability, and suitability.

Flutter has the ability to use a single across multiple platforms such as iOS and Android, ensuring

portability. It’s drag and drop widgets allows for a highly responsive user interface, while direct

compilation to native ARM provides excellent performance. However, Flutter faces limitations like larger

application size, and a smaller library ecosystem and community support due to its recent invention.

React Native utilizes JavaScript, a widely used language with many libraries and tools. It also uses native

components (UI) to create the app’s user interface, providing a smoother and quicker performance. React

native applications usually require a lower minimum SDK version, making it lighter. However, it’s

dependency on native modules can impact performance and Its development process as it requires

knowledge of react and native UI components. Additionally, it may experience occasional UI

inconsistences [30]

In conclusion, Flutter’s various features, including the drag and drop capabilities and excellent

performance, make it a better platform for efficient mobile application development.

Mobile Application Platform | Advantages | Disadvantages
Flutter | • Single codebase for iOS and Android • Drag and drop widgets • Direct compilation to native ARM | Larger application size Smaller library ecosystem Limited community support
React | • Uses native component, resulting in a smoother performance • Requires minimal SDK • Extensive libraries and tools | • Dependency on native modules, affecting the performance • Requires knowledge of react • UI inconsistencies

Table 11: Trade-off Analysis Software Development Platform

6.7.2 IDE
For choosing an IDE, Arduino and Thonny, an IDE used in Raspberry Pi were evaluated on several factors

such as compatibility and portability. The Arduino IDE supports multiple platforms such as MacOS,

Windows and Linux, and offers useful features such as automatic board detection and autosave when

compiling. However, it can be somewhat difficult to navigate, especially for a beginner and lacks

debugging capabilities [31] [32].

Thonny, in comparison offers a more beginner friendly environment with a built-in python interpreter and

step by step debugging. However, it also ha limitations such as the lack of autosave when compiling, and

limited extensibility [33].

In conclusion, the several features of Arduino such the support of multiple platforms and autosave

compiler make it more suitable.

IDE | Advantages | Disadvantages
Arduino | • Support multiple platforms • Automatic board detection • Autosave when compiling | • A bit complex to navigate • Lacks debug capability • Lacks advanced features
Thonny | • Easy to navigate for beginners • Built in python interpreter • Step by step debugging | • Requires saving when compiling • Limited features • Not extensible as other IDEs

Table 12: Trade-off Analysis of IDE

6.7.3 Database
When comparing Firebase and MySQL, there are several differences to note. Firebase offers a NoSQL

database, real-time data synchronization, and a serverless architecture. However, Firebase faces several

limitations such as limited support for server-side architecture, vendor Lock-ins and restricted

customization options. These limitations can be a problem for developers requiring server-side logic or

looking to build complex projects [34].

MySQL is known for its ease of use, support for multiple operating systems and open-source feature

allowing for easy modification. However, it lacks in scalability and flexibility, and may encounter

performance issues [35].

Firebase’s ability to synchronize data in real-time combined with its NoSQL system, makes it highly

suitable for our application.

Database | Advantages | Disadvantages
Firebase | • NoSQL • Real-time data synchronization. • Serverless architecture | • Limited support of server-side languages • Vendor Lock-in • Limited customization
MySQL | • Easy to use • Supports multiple operating systems • Open source | • Less scalability • Lacks flexibility • Performance issues

Table 13: Trade-off Analysis of Database

6.7.4 3-D Drawing Tool
When comparing Fusion 360 and AutoCAD, several features were compared. Fusion 360 has a steeper

learning curve, but offers animation and simulation features, making it more useful in designing a durable

3D model. It is also more affordable, which is an important factor to consider when designing a product.

However, it has some limitations such as a lack of personalized keyboard controls, potential internet

connection issues since it’s a cloud-based application, and limited customization options [36].

In comparison, AutoCAD offers an easier interface to navigate, excelling in 2D and 3D crafting and supports

APIs for extensive customizations. However, it lacks web browser support, limited CAM capabilities, and

subscription-based pricing [37].

Given this analysis between the two software tools, Fusion360’s animation and simulation features makes

it more suitable for our project.

Database | Advantages | Disadvantages
Fusion 360 | • Steeper learning curve • Animation and simulation features • More affordable | • Lacks personalized keyboard controls • Internet connection issues • Lacks customization
AutoCAD | • Easier interface to navigate • Excels in 2D/3D crafting • Supports APIs for customizations | • Lacks web browser support • Limited CAM capabilities • Subscription based pricing

Table 14: Trade-off Analysis of 3-D Drawing Tool

## 7 Implementation

### 7.1 Frontend Implementation

7.1.1 Page Initialization

Implementing the designed user interface in Flutter starts by initializing the pages mentioned in section

5.1. To initialize a page, you create a new blank page and enter a name for that page. After which, you

insert the desired elements of the page, such as text, buttons, and icons. All elements are configured as

static elements initially, and then can be set to have dynamic characteristics at a later stage. It would be

otherwise extremely difficult to attempt to assign dynamic behavior to element at an early stage of the

development, which would introduce unnecessary complexity and high coupling between the different

pages and their corresponding elements, thus making the application susceptible to bugs and errors.

Once all the pages have been initialized with their elements, we now started to configure these elements

according to our design. We started with configuring the text elements to ensure we have the appropriate

text formatting prior to configuring buttons. Otherwise, it is likely that we would have to reformat the

pages’ layouts due to overcrowding.

7.1.2 Dynamic Variables

For the dynamically updated elements, such as the sensor measurements and E. coli levels, they were

configured using the “assignFromVariable” function. This function allowed us to dynamically set a value

of an element by querying a database table, caching the data returned by the query, then displaying this

data within an assigned field in the user interface. The database query needed to be performed at the

page parent level in order to work correctly. The page parent level is the layer at which the topmost

element is located, which is the first element that was placed on the page.

7.1.3 Dynamic Elements and Characteristics

For nested dynamic element characteristics that require query data processing prior to executing a

specific function, such as setting a text highlight color in the dashboard and E. coli pages based on the

measurement value, we utilized the “assignFromVariable” function used previously. However, in this case

we used it along with an if conditional block. In particular, the function compares a specific value retrieved

from the database to a set of possible values. Once the actual value is matched to one of the expected

values, the function returns a parameter containing a hexadecimal color code object to the element

configurator, which in turn sets the highlight color of a text object on the page. This approach was also

used in setting the “Is it consumable?” and “Overall rating” elements on the dashboard page by passing

the raw sensor data to a function that calculates the appropriate value to display on the interface.

7.1.4 Single-Action Buttons

To implement the buttons’ navigation features and actions, we utilized the “setAction” and “navigateTo”

functions. These functions allow us to define how the interface reacts to the users’ button pressing

actions. For navigation buttons, we used the “navigateTo” function to set the page that the interface

should transition to upon the button press. As such, the interface navigates back to the previous page

when pressing on the left arrow icon in the upper left corner from any page. For buttons that navigate

forward in the interface, we set the “navigateTo” function parameter as the name of the desired page to

transition to next, such as the “Let’s get started” button on the welcome page transitions to the log in

page, “Settings” and “Analytics Dashboard” buttons on the home page, “Sign in” button on the login page,

and each of the sensor names on the dashboard page.

7.1.5 Multi-Action Buttons

As for buttons with non-navigation related functions, such as the “Measure” button on the dashboard

page, the “Log out” button on the settings page and the “Sign in” button on the login page, we utilized

the “customAction” function. This function allows us to define complex and multi-action button functions.

The “Measure” button function is to request an instant measurement from the sensors in real-time, this

is achieved by requesting a data update from the Arduino microprocessor. The Arduino then updates the

Firebase “sensorData” table with the new measurements and closes the request, informing the

application that the new measurements are now available. The mobile application then overwrites the

previously cached sensor readings with the new data and automatically updates all the elements related

to these readings.

For the “Sign in” and “Log out” buttons, we utilized the global Flutter parameter named “isUserAuth” to

keep track of whether the user is currently signed in and signed out. When the user presses “Sign in” from

the log in page, the “isUserAuth” parameter is set to true using a “customAction” function that checks if

the user authorization was completed successfully. In case the signed in user presses on the “Log out”

button in the settings page, a secondary “customAction” function is called to change the value of the

“isUserAuth” parameter to false, this triggers another function named “navigateTo” in order to transition

the interface back to the log in page.

### 7.2 Backend Implementation

7.2.1 Firebase-Application Link

The backend implementation started by connecting the designed Firebase database [reference section

5.1] to Flutter and the Arduino microprocessor. Firebase is able to generate a configuration file with all

the variables that are needed by an application in order to access the database and its content. The

configuration file was obtained from the Firebase dashboard then was made accessible to the Flutter project and the Arduino scripts by saving a copy of it to the parent directory of the Flutter project and

Arduino scripts.

The configuration file is formatted in Json to enable the application to fetch the specific variables by

performing a search within the configuration file using the inherent parent-child relationship of data

contained within a Json file. As such, the environment variables were then instantiated with the

corresponding values from the Json configuration file.

Flutter automatically recognizes the Firebase variables defined and configures the “users” table schema

with the appropriate number of columns and their corresponding names. Additionally, Flutter deploys a

set of rules for the Firebase database in order for the encryption mechanism to function correctly. It is

critical that the “users” table is not modified manually under any circumstances to ensure the integrity of

the link between Flutter and Firebase.

There is a Firebase SDK available for the Arduino microprocessor that enables it to communicate with the

database and it needs to be installed prior to performing any Firebase operations from the Arduino. The

Firebase SDK named “FirebaseAdmin” was installed at the same location as the Firebase configuration

file, which is the parent directory of the Arduino.

7.2.2 Firebase Data Update and Query

An integral function of the mobile application is making the sensor measurement available to the user. To

achieve this, the Arduino relays the measurements produced by the sensors to the Firebase database.

Firebase acts as an intermediary host between the mobile application and the Arduino, by storing the

sensor data, enabling the mobile application to query and fetch the needed data. Additionally, it enables

automatic data refresh in the application when the Arduino updates the Firebase measurements with

more recent data.

The Firebase configuration performed by Flutter previously allows it to detect when a data update occurs.

As such, it can automatically fetch the updated data and overwrite the outdated data cached at an earlier

time.

The Arduino microprocessor was programmed to record the sensors’ measurements periodically,

specifically, every 20 seconds. Once this periodic function is triggered, the sensor measurements are read

from the sensors, then saved locally in a temporary variable. Once the sensor measurements have been

collected, they are inserted into the “sensorData” Firebase table using the “db.set()” function provided by

the Firebase SDK. After which, the mobile application refreshes its cached data and updates the interface

to reflect the updated measurements.

For the E. coli measurements provided by the City of Ottawa, the Arduino fetches the Excel file from the

city website every 24 hours. The latest measurements are then extracted and inserted into the “eColi”

database table. Since the measurements are from the previous day, we also wanted to account for rainfall

as it causes the E. coli levels to increase. This was achieved by utilizing an API provided by Open Weather.

To fetch the rainfall forecast, we passed the latitude and longitude of Ottawa within an API call, the API

then sends back a Json file with all the weather data for Ottawa. Then we extract the rainfall amount from

the Json file by filtering the data using “daily.rainfall”, returning the rainfall amount in millimeters. If the

value is larger than zero, then we set the rainfall row of the “eColi” table to true, otherwise, it is set to

false.

7.2.3 Data Processing

Some dynamic elements of the application rely on the processing of raw data in the backend in order for

them to function correctly. The dynamic elements that require this include the “Overall rating”, “Is it

consumable?”, and the measurements’ status on the dashboard page.

The “Overall rating” element provides an overall score out of 5 for the water quality based on the EC, pH,

TSS, and TDS measurements. The mechanism calculates the score by assigning a score for each of the

quality metrics, then sums the 4 individual scores to obtain an overall score out of 5 points. Based on the

measurement of each quality metric, a score of 0, 0.625, or 1.25 will be assigned to that metric.

Additionally, the measurement status and “Is it consumable?” elements utilize the overall score

calculation function. For the measurement status, a status of “Poor”, “Fair”, or “Good” is assigned to each

metric based on whether the individual metric score was 0, 0.625, or 1.25 (respectively). Also, each status

is highlighted in the corresponding color for a more visually pleasing user experience. Where a “Good”,

“Fair”, or “Poor” status is highlighted in green, purple, or orange (respectively).

For the “Is it consumable?” element, it provides a general decision about whether the water can be

consumed by displaying either a “Yes” or “No” answer. It is based on the previously calculated overall

score where if the total score is less than 1.8, a “No” answer is displayed, and if the sum is equal to or

more than 1.8, then a “Yes” answer is displayed. However, there is one exception to this mechanism, if

the pH was assigned a “Poor” status, then an answer of “No” is automatically displayed. Also, a disclaimer

was added to the mobile application informing the user that the system is unable to detect pathogens

and micro-organisms in the water, in order to avoid any ambiguity with the “Is it consumable?” element

of the dashboard page. The table below outlines the range of values for status and score assignment of

each quality metric.

Metric / Rating | Good (1.25 points) | Fair (0.625 points) | Poor (0 points)
EC | value < 0.3 | 0.3 <= value <= 0.8 | value > 0.8
pH | 7 <= value < 9 | 9 <= value <= 10.2 | value > 10.2 or value < 7
Turbidity | value < 500 | 500 <= value < 1500 | value >= 1500
TDS | value < 150 | 150 <= value <= 400 | value > 400

Table 15: Score and Rating Assessment Mechanism Values

For the E. coli status on the dashboard page, a function checks if all the levels are below the threshold of

200 and whether there has been any rainfall in the past 24 hours. If all the values are below the threshold

and there has been no rainfall, then the status is set to “Good”. If the E. coli levels are all below the

threshold and there has been rainfall, then the status is set to “Poor”. If at least one of the E. coli levels is

below the threshold and there has been no rainfall, then the status is set to “Fair”. On the E. coli page that

displays the measurement of each beach or river, each measurement is highlighted in Green or Orange

based on whether that specific measurement is below or above the threshold (respectively), except for

when there has been rainfall in the past 24 hour, then the measurements are all highlighted in Orange.

7.2.4 Inter-node Communication

In order to implement the real-time measurement feature of the mobile application, a communication

link was needed to connect the mobile application and the Arduino microprocessor. This was achieved by

utilizing the real-time functionality of Firebase. A third Firebase database named “liveMeasure” containing

one field was created, and the field was initialized with the integer 0. When the user requests a new

measurement by pressing the “Measure” button on the dashboard page, the integer stored in

“liveMeasure” is overwritten with 1. The Arduino script continuously checks if there has been a data

update, once this is detected by observing the change of the stored value from 0 to 1, it records the sensor

data and inserts them into the “sensorData” table and overwrites the integer stored in “liveMeasure” with

0. Simultaneously, the mobile application detects the data update in both the “sensorData” and

“liveMeasure” tables, after which, it overwrites the cached sensor data with the updated data, which are

then displayed to the user.

7.2.5 User Authorization

The user is provided with multiple methods to sign in to the application. They have the option to use a

conventional email and password configuration, Google sign in, or Apple sign in. This improves the user

experience by providing flexibility and convenience.

If the user elects to use a conventional email and password to sign in, they will be required to use a

minimum password length of 8 characters, include one upper case and one lower case letter, and include

one number. Their sign in information is then encrypted and stored in the “users” database.

If the user elects to use Google or Apple sign in, they will be directed to the appropriate website to

continue the sign in process. Once they complete the sign in process with Google or Apple, the user

information (excluding their password) is passed back to the application, which creates a new user

account using the information passed, then encrypts and stores the profile information in the database.

The next time they attempt to sign in to the application, the application recognizes their existing profile,

and their information is retrieved.

7.2.6 Sensor Integration

To integrate the sensors once connected to the Arduino board, we installed several libraries such as

Arduino DFRobot and Firebase which are required to run the script and obtain readings. We then defined

the pins to ensure each reading was properly acquired. We then wrote the complete script to read the

values from each sensor using a void() and loop(), which is a requirement of the Arduino IDE. We also

included the firebase credentials allowing for data storage. Once the values are obtained, they are stored

in Firebase database in real-time.

### 7.3 Hardware Implementation

To implement the hardware component, several sensors were connected to the Arduino Uno through a

breadboard, which controls them using a sketch in the Arduino IDE. Each sensor is connected to three

pins: an analog input, ground and power. The Arduino Uno has six analog pins (A0 to A6), two 5V pins,

two ground pins, a 3.3V pins, and fourteen digital pins (D0-D13).

The pH sensor was connected to analog pin A5, the EC sensor to analog pin A2, the turbidity sensor to

analog pin A0, and the TDS sensor to analog pin A3. The temperature sensor, which has a digital input was

connected to digital pin D5. To power the sensors, the Arduino board is connected to a rechargeable

battery, providing ease of use and minimal hardware requirements.

The pH and EC sensors must be calibrated for accurate readings using calibration solutions provided by

the manufacturer. The pH sensor is entered into calibration mode via the serial monitor command

“enterph” and then placed in a 7 pH or 4 pH calibration solution. Similarly, the EC sensor is entered into

calibration mode using the “enterec” command. The system will automatically the solution and adjust to

the correct value.

Additionally, the water bottle is made using ABS material. This is due to its known durability, and strength.

It is also important to note that it is food-safe and used products that come in contact with liquids such as

water, making it an excellent choice for this application [32].

## 8 Testing

Given the sensitive nature of this project, where improper or inaccurate system behavior could pose

health risks to the user, extensive testing was conducted to verify that the system components are

functioning correctly. Testing was partitioned into two parts, software testing and hardware testing. The

software portion covers the mobile application functions, Arduino scripts, and the Firebase database. The

hardware part of testing covers the sensors and their accuracy.

### 8.1 Software Testing

8.1.1 Mobile Application Testing

We thoroughly tested the mobile application thoroughly in order to ensure all the elements behave as

expected. Due to the rapid testing feature of Flutter, we were able to compile the mobile application and

test it on a virtual device within a web browser. This also allowed us to check the performance of the

mobile application throughout the testing to make sure the app stayed responsive throughout the tests

performed.

We first tested all the navigation buttons to verify the correct transitions take place while navigating the

different pages. Then we tested the behavior of complex buttons, which trigger the execution of functions

in the backend, to ensure the functions are accessible within the current app state and return correct

parameters or values back to the function caller.

Once the mobile application was confirmed to be functioning as expected, we tested the mobile

application in integration with the Firebase database. We started by manually inserting test values into

the database tables, then simulating a user action that would cause the application to fetch the data from

the database and process it accordingly. In particular, we were testing the ability of the application to

identify the correct set of data in the database, obtain that data, and then process it correctly. During this step, we identified a bug that causes the application to become unresponsive and crash. The issue was

related to a while loop that filters the data fetched from the database, where it would keep iterating

infinitely when none of the conditions within it are satisfied. To address this issue, we added an additional

condition that forces the while loop to return an error code when none of the conditions have been

satisfied.

After the mobile application and database were tested, we introduced the Arduino into the testing

procedures we previously completed with the exception that all the functions’ logic of the Arduino scripts

were stubbed in order to isolate the testing only to the communication between the system components.

At this stage, we tested the ability of the Arduino to access the database and communicate with the

mobile application. Once we were sure that all the components were functional, we moved on to unit

testing the Arduino scripts to ensure all the function logic is correct and bug free.

8.1.2 Arduino Testing

Testing the Arduino script is important to ensure the data is displayed and sent to the firebase successfully.

A popular software testing library called unitTest, is available in the Arduino IDE as ArduinoTest. This

library was used to test to verify matching values using “assertEquals()”. To verify the data is sent and

retrieved correctly, we implemented a function “TestFirebase()” inside the test script “Testarduino”.

Inside the function, instances of “read[sensor_name]()” are initialized to retrieve the sensor readings and

then pushed to firebase using the built-in function “pushFloat()”. The instances of each reading are then

compared against the firebase values using the “assertEquals()”. Similarly, for testing the accuracy of

displayed output, sensor readings are compared with values printed in the serial monitor to verify the

correct output. This was done by implementing a function “TestDisplayOuput()”, which calls and asserts

the instances of the sensors with the “Serial.print()” function.

### 8.2 Hardware Testing

The hardware testing portion proved to be the most critical as the sensors are the source of data in our

system and we must verify both the accuracy and correctness of measurements they produce. We needed

to design a set of tests that allow us to compare the actual measurements to the expected measurements

of that sensor. This was achieved by formulating multiple solutions of known concentrations, which we

can then measure with the appropriate sensor, and compare the results. This testing procedure also

helped us in confirming the validity of the calibration performed by the manufacturer. We also used the

test results to analyze the transient response characteristics of the sensors. Most importantly, we need

to ensure the standard solutions used in testing the sensors were sourced from a reputable source in

order to be confident in our results. As such, the standard solutions were obtained from an organization

named “Hach”, which specializes in water quality testing and is considered an industry leader due to their

proven track record and reputation.

8.2.1 Temperature Sensor Testing

The first sensor we tested is the temperature sensor. This is because the temperature is needed for

accurately measuring pH, EC, and TDS. Thus, it is essential to ensure the temperature sensor is functioning

correctly before moving on to the other sensors. In order to test the temperature sensor, we boiled

distilled water in a clean kettle then we measured the temperature of the water using the temperature

sensor. We used a sampling rate of 100Hz and collected measurements for 3 seconds. We then plotted

the collected data as shown in the figure below:

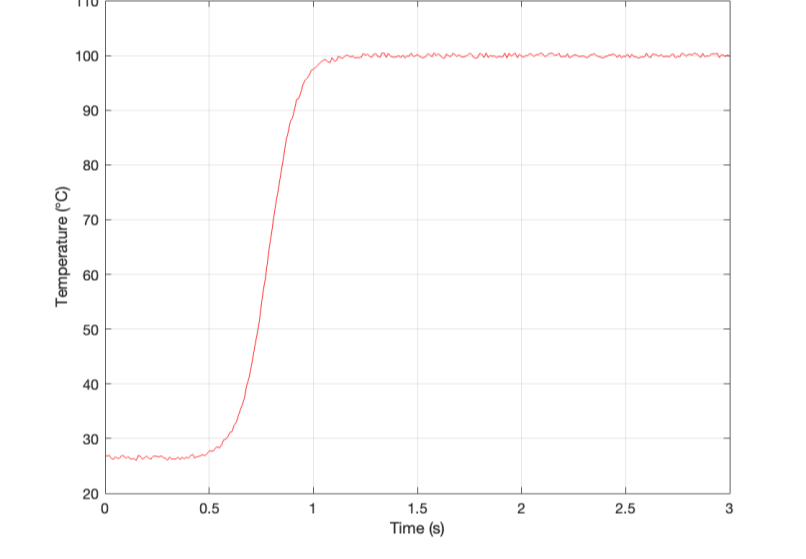
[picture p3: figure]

Figure 1: Temperature Sensor Response for Boiled Distilled Water (100 °C)

The temperature sensor settling time was 0.8 seconds, which is similar to the manufacturer specification

of 0.75 seconds. Additionally, we can see that it is functioning correctly as the steady state output value

is approximately 99.7 °C. Therefore, we can conclude that the temperature sensor is functioning correctly,

and it passed the test.

8.2.2 Turbidity Sensor Testing

In order to test the turbidity sensor, we purchased a 4000 NTU standard solution which we used to

formulate three solutions of 1000 NTU, 500 NTU, and 100 NTU. In order to dilute the standard solution

down to the desired concentrations, we used the following formula to calculate the needed volume of

the standard solution:

C1V1 = C2V2

Where C1 is the concentration of the standard solution, V1 is the volume of standard solution needed, C2

is the concertation of the diluted solution, and V2 is the volume of the diluted solution. Since we only need to calculate the volume of standard solution we need to use, we can rearrange the equation as

follows:

V1 =

C2V2
C1

We then used the above formula to calculate the required volume of standard solution for each diluted

solution as per the following table:

Volume of standard solution (V1) | Concentration of diluted solution (C2) | Volume of diluted solution (V2) | Concentration of standard solution (C1)
25 mL | 1000 NTU | 100 mL | 4000 NTU
12.5 mL | 500 NTU | 100 mL | 4000 NTU
2.5 mL | 100 NTU | 100 mL | 4000 NTU

Table 16: Turbidity Sensor Test Solutions Dilution Calculations

We then formulated each of the three solutions by mixing the specified volume of standard solution into

distilled water, please note that the volume of distilled water to use for each diluted solution is the

difference between the volume of diluted solution and the volume of standard solution as follows:

volume of distilled water = V2 − V1

Once the diluted solutions were formulated, we tested the turbidity sensor by measuring the turbidity of

each of the diluted solutions and made sure to thoroughly rinse the sensor probe with distilled water

between each test. Then we plotted the collected data to facilitate the analysis of results. The following

figures show the collected measurement data for each of the diluted solutions:

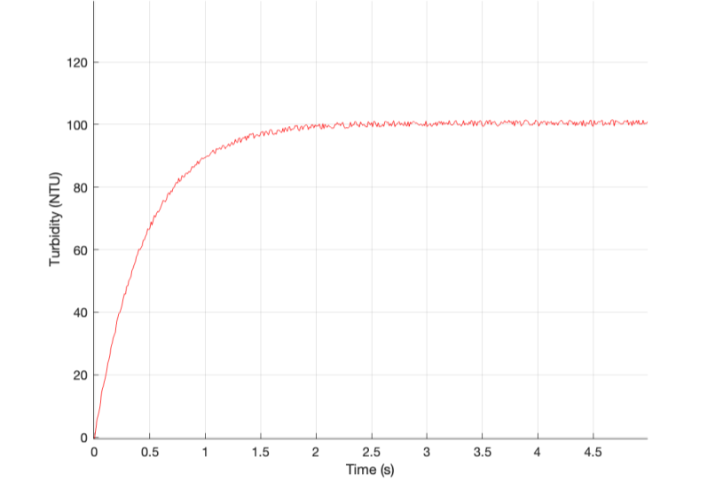
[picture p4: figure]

Figure 2: Turbidity Sensor Response for 100 NTU Test Solution

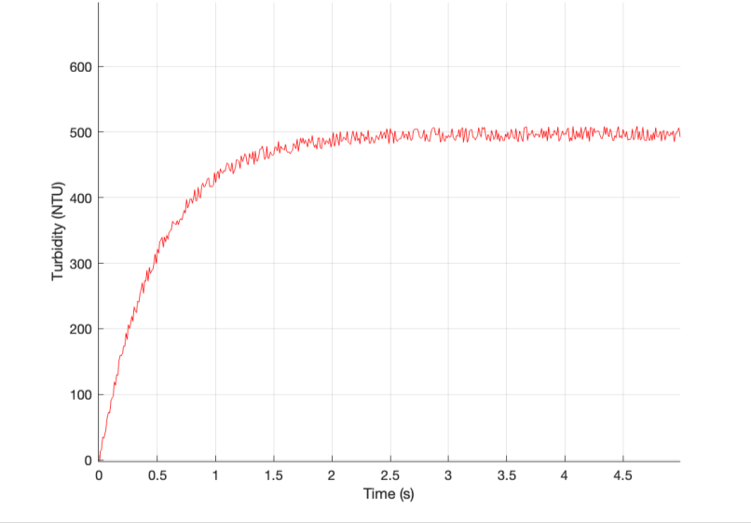
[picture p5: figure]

Figure 3: Turbidity Sensor Response for 500 NTU Test Solution

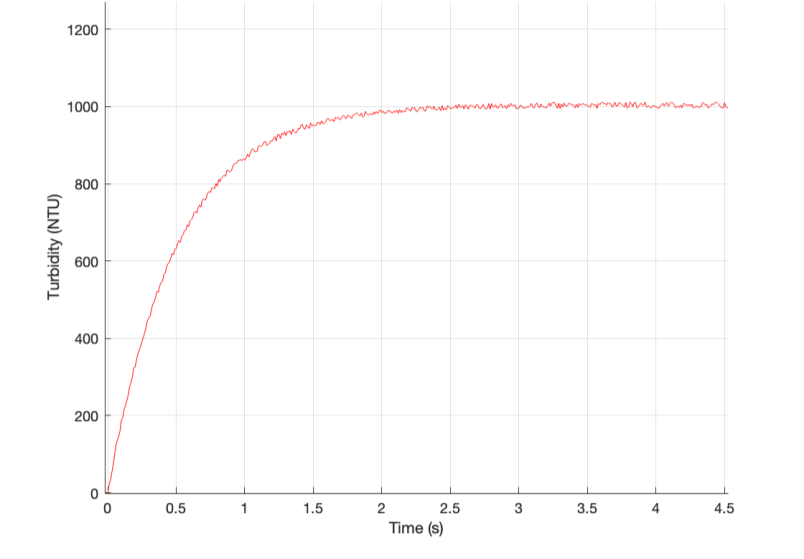
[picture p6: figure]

Figure 4: Turbidity Sensor Response for 1000 NTU Test Solution

The manufacturer specifications state that the settling time of the turbidity sensor is 2 seconds. In our

testing, we found the settling time to be 1.9 seconds on average, which indicates the sensors’

performance is better than what the manufacturer anticipated. The measurements were consistently

accurate across the three solutions we tested, with an accuracy of ± 3 NTU, indicating they are functioning

correctly. Therefore, we can conclude that the turbidity sensor has passed the tests.

8.2.3 Electrical Conductivity Sensor Testing

In order to test the EC sensor, we purchased a standard solution with a conductivity of 3960 µs/cm in

order to prepare 3 test solutions. This was achieved by diluting the standard solution accordingly using

the same method from section 8.2.2 Turbidity Sensor Testing. The test solutions were formulated

according to the following table:

Volume of standard solution (V1) | Concentration of diluted solution (C2) | Volume of diluted solution (V2) | Concentration of standard solution (C1)
46.7 mL | 1850 µs/cm | 100 mL | 3960 µs/cm
24 mL | 920 µs/cm | 100 mL | 3960 µs/cm
8.8 mL | 350 µs/cm | 100 mL | 3960 µs/cm

Table 17: EC Sensor Test Solutions Dilution Calculations

The EC sensor was then used to measure each of the test solutions while making sure to thoroughly rinse

the sensor probe between the tests. For each test, the sensor data output was logged for 5 minutes to

ensure the sensor measurement had ample time to settle, then we plotted the data to analyze it. The

following figures show the sensor response for each of the test solutions:

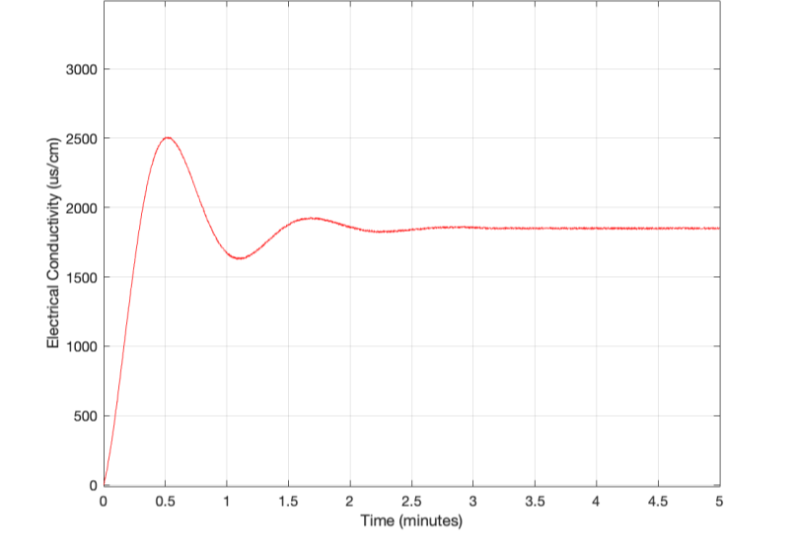
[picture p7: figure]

Figure 5: EC Sensor Response for 1850 µs/cm Test Solution

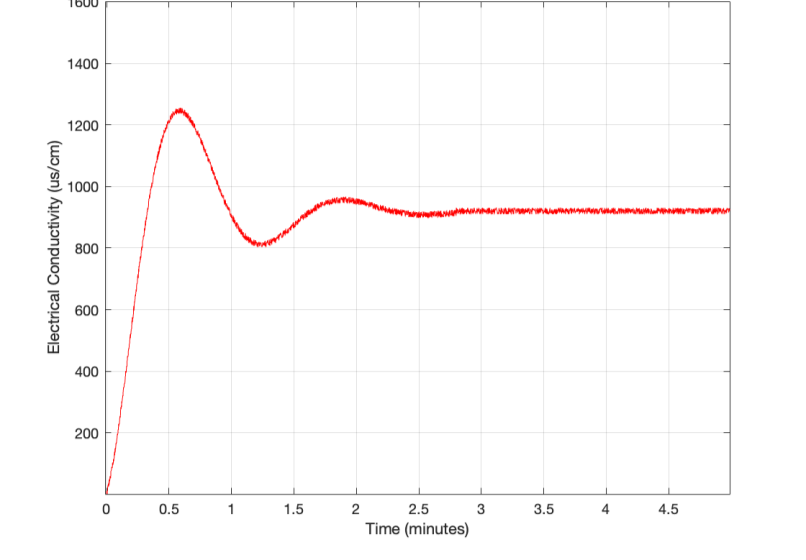
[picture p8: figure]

Figure 6: EC Sensor Response for 920 µs/cm Test Solution

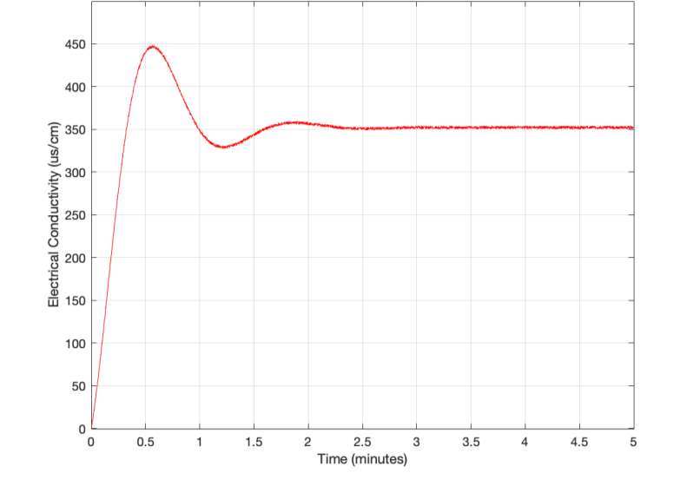
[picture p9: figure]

Figure 7: EC Sensor Response for 350 µs/cm Test Solution

We observed that the readings fluctuate initially when the sensor is placed in each of the solutions before

stabilizing and providing a constant measurement. Although the manufacturer does not provide a settling

time specification, we found that on average it takes 3 minutes for the readings to stabilize. The steady

state output values for each of solutions tested were within ± 5 µs/cm of the expected value, indicating the sensor is functioning as expected. Therefore, we can conclude the EC sensor has successfully passed

the tests.

8.2.4 Total Dissolved Solids Sensor Testing

In order to test the TDS sensor, we used the same standard solution from the EC sensor tests as it is also

rated with a TDS content of 3000 ppm. Similarly, we prepared three solutions of varying TDS content in

order to perform the tests for the TDS sensor. The test solutions were formulated as per the following

table:

Volume of standard solution (V1) | Concentration of diluted solution (C2) | Volume of diluted solution (V2) | Concentration of standard solution (C1)
30 mL | 900 ppm | 100 mL | 3000 ppm
13.7 mL | 410 ppm | 100 mL | 3000 ppm
4 mL | 120 ppm | 100 mL | 3000 ppm

Table 18: TDS Sensor Test Solutions Dilution Calculations

Once the test solutions were prepared, we used the TDS sensor to measure the solutions while logging

the data output of the sensor for 10 seconds. The logged output data was then used to plot the following

response figures:

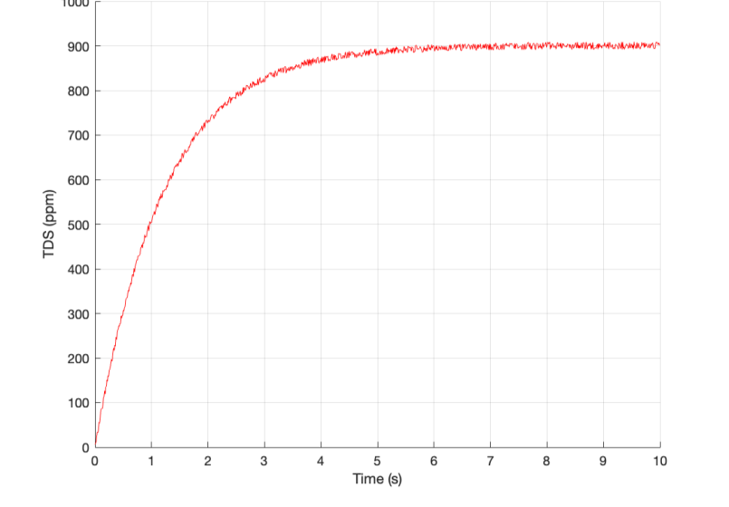
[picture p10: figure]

Figure 8: TDS Sensor Response for 900 ppm Test Solution

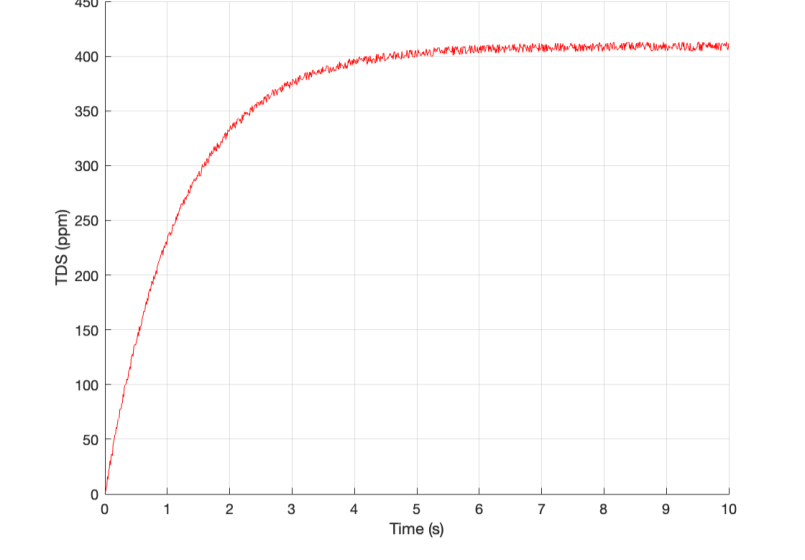
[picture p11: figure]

Figure 9: TDS Sensor Response for 410 ppm Test Solution

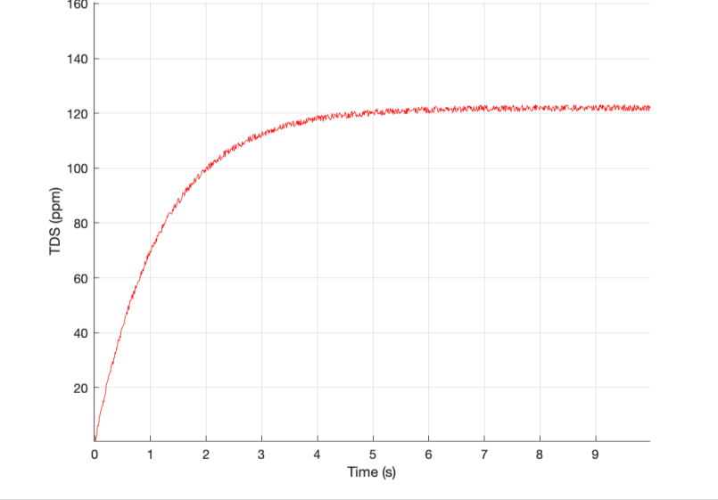
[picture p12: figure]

Figure 10: TDS Sensor Response for 120 ppm Test Solution

We observed the TDS sensor response to have an average settling time of 5 seconds. Although the

manufacturer did not specify a settling time for the sensor, the response was consistent across the 3 tests

we performed. We also observed the steady state output values to be accurate and within ± 9 ppm of the

expected result for each solution. Therefore, we can conclude that the TDS sensor has successfully passed

the tests as it is functioning as expected.

8.2.5 pH Sensor Testing

In order to test the pH sensor, we purchased 3 standard solutions of pH values of 4.01, 7.0, and 10.01. We

then followed the same testing procedure as for the other sensors. The manufacturer specifications state

that the pH sensor has a settling time of 8 minutes, as such, we logged the sensor measurements for 10

minutes in order to provide the sensor with adequate time to allow the measurements to stabilize. The

measurement data was then plotted to visualize the sensor response as shown in the following figures:

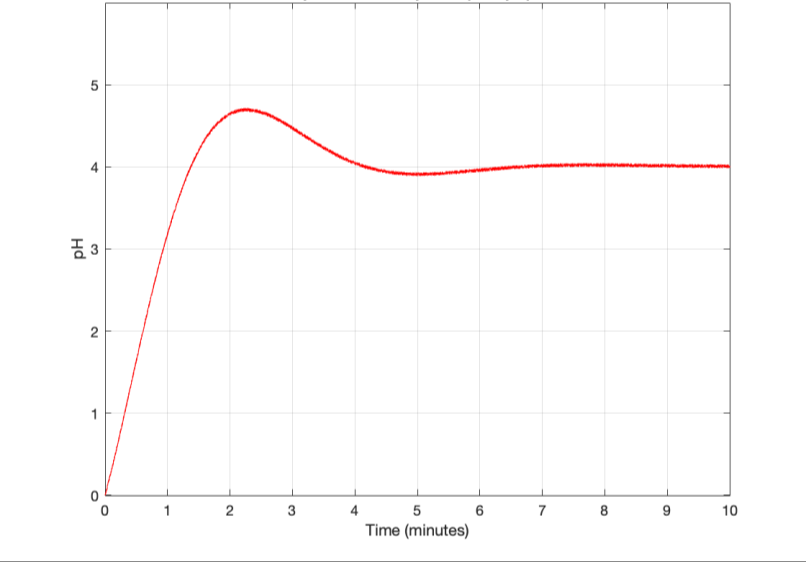
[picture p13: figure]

Figure 11: pH Sensor Response for 4.01 pH Test Solution

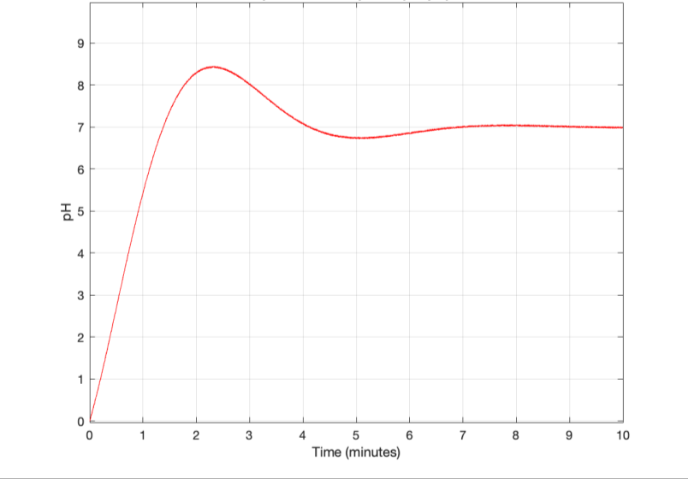
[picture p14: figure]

Figure 12: pH Sensor Response for 7.0 pH Test Solution

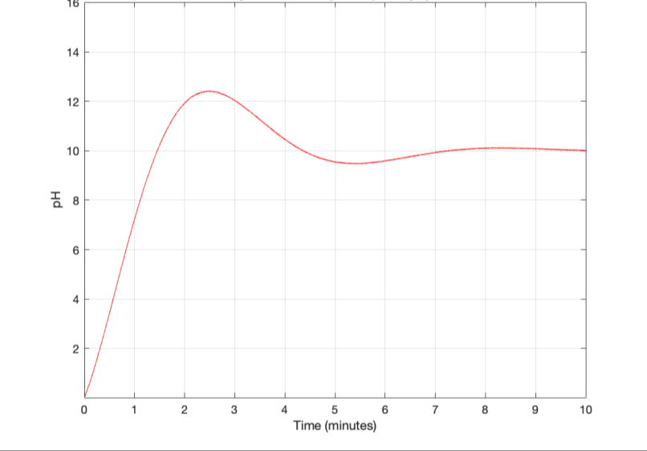
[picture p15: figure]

Figure 13: pH Sensor Response for 10.01 pH Test Solution

We observed the average settling time to be 8 minutes, which is exactly what the manufacturer stated.

Additionally, the steady state output values were consistent and within ± 0.09 of the expected values

across all the tests. Therefore, we can conclude that the pH sensor has successfully passed the tests as its

behavior aligns with the expected values.

## 9 Project Milestones

Below is the updated project timetable with all the major milestones’ deadlines. The project Gantt chart

with all the other milestones completed throughout the project is attached in the Appendix [Appendix C:

Project Progression Gantt Chart].

Milestone | Due Date
Project Proposal | January 26, 2024
HW/SW Request Form | February 9, 2024
Progress Report | April 22, 2024
Oral Presentation | April 26, 2024
Poster Fair | June 14, 2024
Final Report and Video | July 5, 2024

Table 19: Major Project Milestones and Due Dates

## 10 Conclusions and Reflections

### 10.1 Conclusions

The focus of our project was to implement a portable and smart drinking water quality monitoring system,

in order to address the lack of availability of such product and the disadvantages of using conventional

paper test strips to measure water quality. The developed system consists of multiple sensors that infer

useful measurements about the water quality, conveniently built into a water bottle, as well as a mobile

application that provides an intuitive user interface for the user to interact with the system. This enabled

the users to be confident in the quality of water they intend to consume, without compromising

convenience or ease of use.

### 10.2 Recommendations for Future Project Extensions

The physical dimensions of the water bottle housing [Appendix B: Water Bottle Housing Engineering

Drawings] are larger than needed. During the design stage of the project, we included extra space in case

it was needed during the implementation stage, which caused the final product to be bulky. The water

bottle housing would greatly benefit from a reduced size to make it more sleek and easier to transport.

Additionally, the updated water bottle housing would benefit from a cap with a built-in flexible straw. This

would facilitate in drinking the water contained in the bottle while not affecting the cap functionality of

sealing the bottle.

Another possible improvement of the water bottle housing would be the use of smaller sized sensors. This

would help in reducing the overall size of the water bottle housing as well. Our initial plan for this project

was to incorporate the sensors into the base of the water bottle. This requires surface mount sensors that

have a very small footprint of approximately 1 cm by 1 cm. Unfortunately, this size of water quality sensors

is not currently available, therefore we had to use conventional sensor probes that have a much larger footprint. If water quality sensors become available in a much smaller size in the future, it would be the

best improvement that can be made to this project.

The wiring and circuitry contained within the bottle housing was slightly messy and fragile. Because all the

sensors were connected to the Arduino through a breadboard. Although a breadboard makes connecting

the hardware components easier, the wires are susceptible to disconnection. To address this, a printed

circuit board can be designed for a more secure connection and better organized wiring.

### 10.3 Reflections

If we were to start the project again, we would have ordered the hardware components earlier than

originally planned. This would have enabled us to start working on the project earlier and would have

given us more hands-on time during the early stages of the project, because we became a little stressed

towards the end of the project due to our deadlines for our summer courses.

Overall, this project was a great experience that although stressful at certain times due to the reduced

team size, it presented us with constructive challenges that helped us learn more and develop a resilient

work ethic. Additionally, it allowed us to apply a large set of knowledge and skills gained throughout our

undergraduate studies, further reinforcing the concepts we learned previously.

Given that all the functional and non-functional project requirement we outlined have been meet, we

consider the project successful.

## References

[1] “What Is Fusion 360? – Simply Explained,” All3DP, Nov. 13, 2019. https://all3dp.com/2/what-is-

fusion-360-simply-explained/ (https://all3dp.com/2/what-is-fusion-360-simply-explained/)

[2] Atlas Scientific, “Does Temperature Affect pH?,” Atlas Scientific, Jan. 12, 2023. https://atlas-

scientific.com/blog/does-temperature-affect-ph/ (https://atlas-scientific.com/blog/does-temperature-affect-ph/)

[3]https://www.researchgate.net/publication/371539432_TEMPERATURE_EFFECT_ON_ELECTRICAL_CO

NDUCTIVITYEC_TOTAL_DISSOLVED_SOLIDS_TDS_OF_WATER_A_REVIEW#:~:text=In%20general%2C%20

as%20the%20temperature,which%20increases%20the%20overall%20conductivity (https://www.researchgate.net/publication/371539432_TEMPERATURE_EFFECT_ON_ELECTRICAL_CONDUCTIVITYEC_TOTAL_DISSOLVED_SOLIDS_TDS_OF_WATER_A_REVIEW)

[4] “What is EC? How can you differentiate between EC and TDS?,” www.westlab.com.

https://www.westlab.com/blog/what-is-ec-how-can-you-differentiate-between-ec-and-tds

[5] D. O’Donnell, “Why Electrical Conductivity of Water is Important for Industrial

Applications,” Sensorex, Oct. 08, 2019. https://sensorex.com/electrical-conductivity-water-important-

industrial-applications/ (https://sensorex.com/electrical-conductivity-water-important-industrial-applications/)

[6] “Why Is pH Important?,” Atlas Scientific, Aug. 07, 2021. https://atlas-scientific.com/blog/why-is-ph-

important/#:~:text=Whether%20it%20be%20for%20drinking (https://atlas-scientific.com/blog/why-is-ph-important/#:~:text=Whether%20it%20be%20for%20drinking)

[7] Atlas Scientific, “How Does A pH Probe Work?,” Atlas Scientific, Oct. 18, 2021. https://atlas-

scientific.com/blog/how-does-a-ph-probe-work/ (https://atlas-scientific.com/blog/how-does-a-ph-probe-work/)

[9] Atlas Scientific, “Why Is Turbidity Important?,” Atlas Scientific, May 14, 2022. https://atlas-

scientific.com/blog/why-is-turbidity-important (https://atlas-scientific.com/blog/why-is-turbidity-important)

[10] [mcoulter, “Chlorination and Turbidity,” Thompson-Nicola Regional District.

https://www.tnrd.ca/services/water-sewage/chlorination-and-turbidity/

[11] “Turbidity_sensor_SKU__SEN0189-DFRobot,” wiki.dfrobot.com.

https://wiki.dfrobot.com/Turbidity_sensor_SKU__SEN0189#:~:text=It%20uses%20light%20to%20detect

(accessed Jul. 01, 2024)

[12] “Best Home RO Water Purifiers Online - Pureit Water India,” www.pureitwater.com.

https://www.pureitwater.com/blog/post/understanding-total-dissolved-solids. (accessed Jul. 01, 2024).

[13] Arduino.cc, 2024. https://docs.arduino.cc/hardware/uno-r4-wifi/
[14] “Arduino® UNO R4 WiFi,” Arduino Official Store. https://store.arduino.cc/products/uno-r4-

wifi#:~:text=Expanded%20memory%20and%20faster%20clock (https://store.arduino.cc/products/uno-r4-wifi#:~:text=Expanded%20memory%20and%20faster%20clock)

[15] “Difference Between Arduino and Raspberry Pi [Comparison Table],” webbylab.

https://webbylab.com/blog/arduino-vs-raspberry-pi-key-differences-comparison-table/

[16] “Arduino vs Raspberry Pi: What’s The Difference?,” InterviewBit, Nov. 11, 2021.

https://www.interviewbit.com/blog/arduino-vs-raspberry-pi/

[17] “A Review of 11 Temperature and Humidity Sensors - DFRobot,” www.dfrobot.com.

https://www.dfrobot.com/blog-45.html (accessed Jul. 01, 2024).

[18] “TMP100_Temperature_Sensor__SKU_TOY0045_-DFRobot,” wiki.dfrobot.com.

https://wiki.dfrobot.com/TMP100_Temperature_Sensor__SKU_TOY0045_(accessed Jul. 01, 2024).

[19] “DS18B20 Temperature Sensor For Arduino - DFRobot Wiki,” wiki.dfrobot.com.

https://wiki.dfrobot.com/Gravity__DS18B20_Temperature_Sensor__Arduino_Compatible__V2_SKU__D

FR0024 (https://wiki.dfrobot.com/Gravity__DS18B20_Temperature_Sensor__Arduino_Compatible__V2_SKU__DFR0024) (accessed Jul. 01, 2024).

[21] “PH_meter_SKU__SEN0161_-DFRobot,” wiki.dfrobot.com.

https://wiki.dfrobot.com/PH_meter_SKU__SEN0161_(accessed Jul. 01, 2024)

[22] “Grove - PH Sensor Kit (E-201C-Blue) - Seeed Wiki,” wiki.seeedstudio.com.

https://wiki.seeedstudio.com/Grove-PH-Sensor-kit/(accessed Jul. 01, 2024)

[23] “PH_meter_SKU__SEN0161_-DFRobot,” wiki.dfrobot.com.

https://wiki.dfrobot.com/PH_meter_SKU__SEN0161_(accessed Jul. 01, 2024)

[24] “Grove - PH Sensor Kit (E-201C-Blue) - Seeed Wiki,” wiki.seeedstudio.com.

https://wiki.seeedstudio.com/Grove-PH-Sensor-kit/(accessed Jul. 01, 2024)

[25] “ec meter - DFR0300 - Gravity: Analog Electrical Conductivity Sensor | DFRobot

Electronics,” www.dfrobot.com. https://www.dfrobot.com/product-1123.html(accessed Jul. 01, 2024)

[26] “Grove - TDS Sensor - Seeed Wiki,” wiki.seeedstudio.com. https://wiki.seeedstudio.com/Grove-TDS-

Sensor/ (https://wiki.seeedstudio.com/Grove-TDS-Sensor/) (accessed Jul. 01, 2024)

[27] “Grove - Turbidity Sensor Meter for Arduino V1.0 - Seeed Wiki,” wiki.seeedstudio.com.

https://wiki.seeedstudio.com/Grove-Turbidity-Sensor-Meter-for-Arduino-V1.0/ (accessed Jul. 01, 2024)

[28] “Gravity: Analog Turbidity Sensor For Arduino - DFRobot,” www.dfrobot.com.

https://www.dfrobot.com/product-1394.html (accessed Jul. 01, 2024)

[29] “Gravity_Analog_Electrical_Conductivity_Sensor_Meter_K=10_SKU_DFR0300-H-

DFRobot,” wiki.dfrobot.com.

https://wiki.dfrobot.com/Gravity_Analog_Electrical_Conductivity_Sensor_Meter_K=10_SKU_DFR0300-H

[30] “Grove - EC Sensor Kit | Seeed Studio Wiki,” wiki.seeedstudio.com, Jan. 06, 2023.

https://wiki.seeedstudio.com/Grove-EC-Sensor-kit/

[31]
“Compare arduino ide vs thonny | DiscoverSDK,” discoversdk, 2015.
http://www.discoversdk.com/compare/arduino-ide-vs-thonny (accessed Jul. 09, 2024).

[32]
“What are the pros and cons of using Arduino IDE vs. other development tools for embedded software?,” www.linkedin.com. https://www.linkedin.com/advice/0/what-pros-cons-using-arduino-ide-vs-other-development (https://www.linkedin.com/advice/0/what-pros-cons-using-arduino-ide-vs-other-development) (accessed Jul. 01, 2024)

[33]
M. Mutwiri, “Choosing the Perfect Python IDE: Pros and Cons of Top Options,” Medium, Nov. 13, 2023. https://python.plainenglish.io/choosing-the-perfect-python-ide-pros-and-cons-of-top-options-2311c53d35a1 (https://python.plainenglish.io/choosing-the-perfect-python-ide-pros-and-cons-of-top-options-2311c53d35a1)

[34]

“Comparing Firebase and MySQL: A Guide for Developers,” Mar. 13, 2024. https://blog.back4app.com/firebase-vs-mysql/#:~:text=Architecture- (accessed Jul. 09, 2024). (https://cmailcarletonca-my.sharepoint.com/personal/ahmadalkawasmeh_cmail_carleton_ca/Documents/University/Capstone/Final%20Report/%0d“Comparing%20Firebase%20a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)

[35]

G. G. Barman, “Difference between MySQL and Firebase? Difference between SQL and
NoSQL,” Medium, Oct. 10, 2020. https://androidapps-development-blogs.medium.com/difference-between-mysql-and-firebase-difference-between-sql-and-nosql-e1ce538f9e17 (https://androidapps-development-blogs.medium.com/difference-between-mysql-and-firebase-difference-between-sql-and-nosql-e1ce538f9e17) (accessed Jul. 01, 2024)

[36]

“Navigating the Basics: AutoCAD vs Fusion 360,” Aircada Pro, Feb. 22, 2024. https://aircada.com/autocad-vs-fusion- (accessed Jul. 09, 2024).

[37]
“AutoCAD v/s Fusion 360: Which Software is Best to Learn in 2024?,” www.novatr.com. https://www.novatr.com/blog/autocad-vs-fusion-360#:~:text=Fusion%20360%20works%20on%20the (accessed Jul. 09, 2024).

[38] “Flutter vs. React Native: Which One to Choose in 2023?,” Simplilearn.com.

https://www.simplilearn.com/tutorials/reactjs-tutorial/flutter-vs-react-native (accessed Jul. 01, 2024)

[39] “CFR - Code of Federal Regulations Title 21,” www.accessdata.fda.gov.

https://www.accessdata.fda.gov/scripts/cdrh/cfdocs/cfcfr/cfrsearch.cfm?fr=177.1020 (accessed Jul. 01,

2024)

## Appendix A: Mobile Application Screens

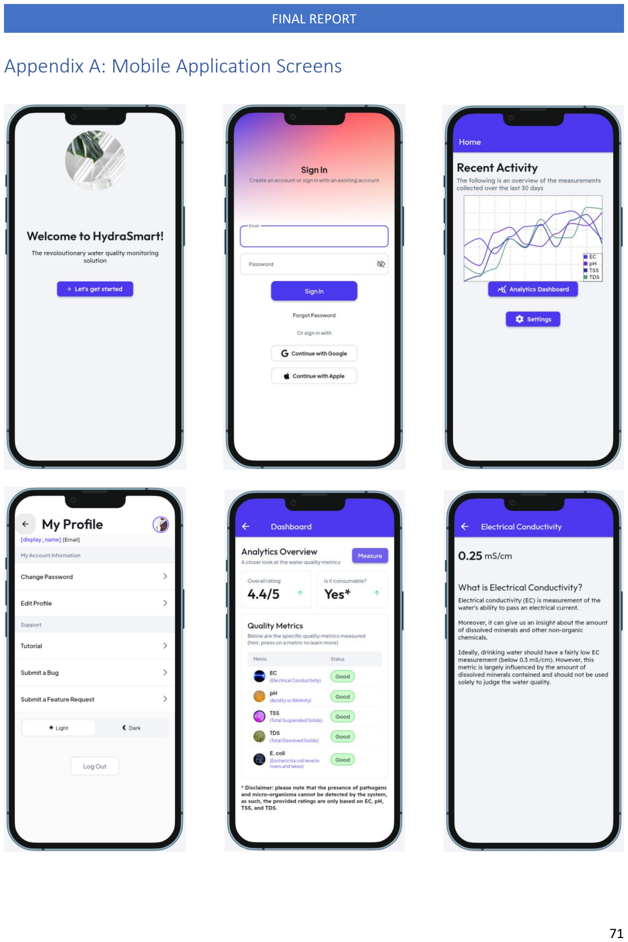
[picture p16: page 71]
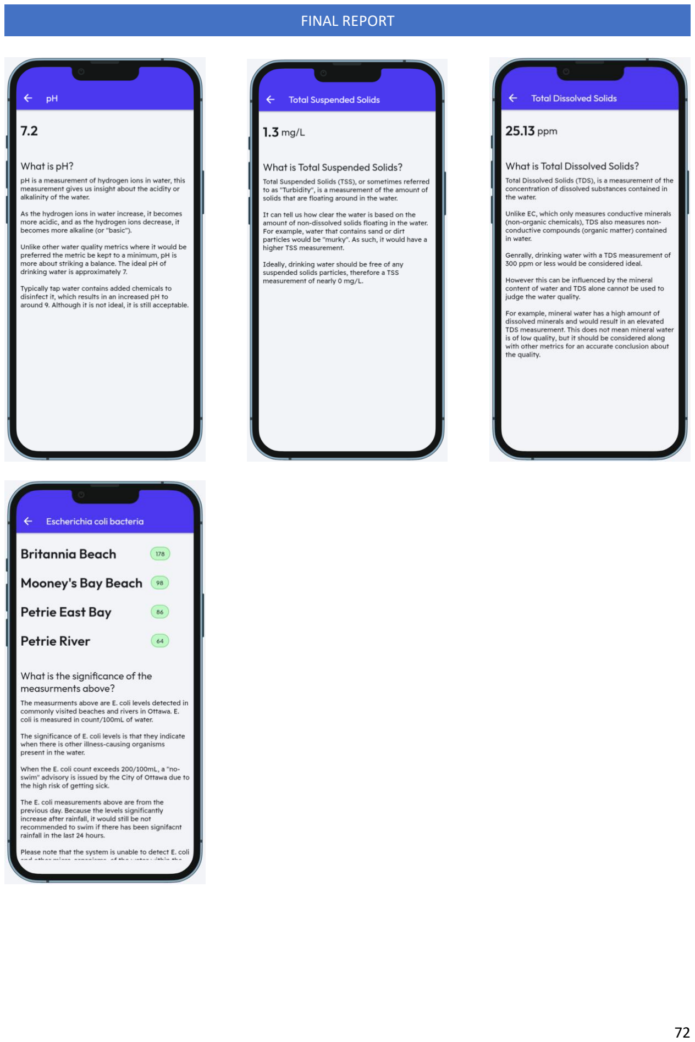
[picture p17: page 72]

## Appendix B: Water Bottle Housing Engineering Drawings

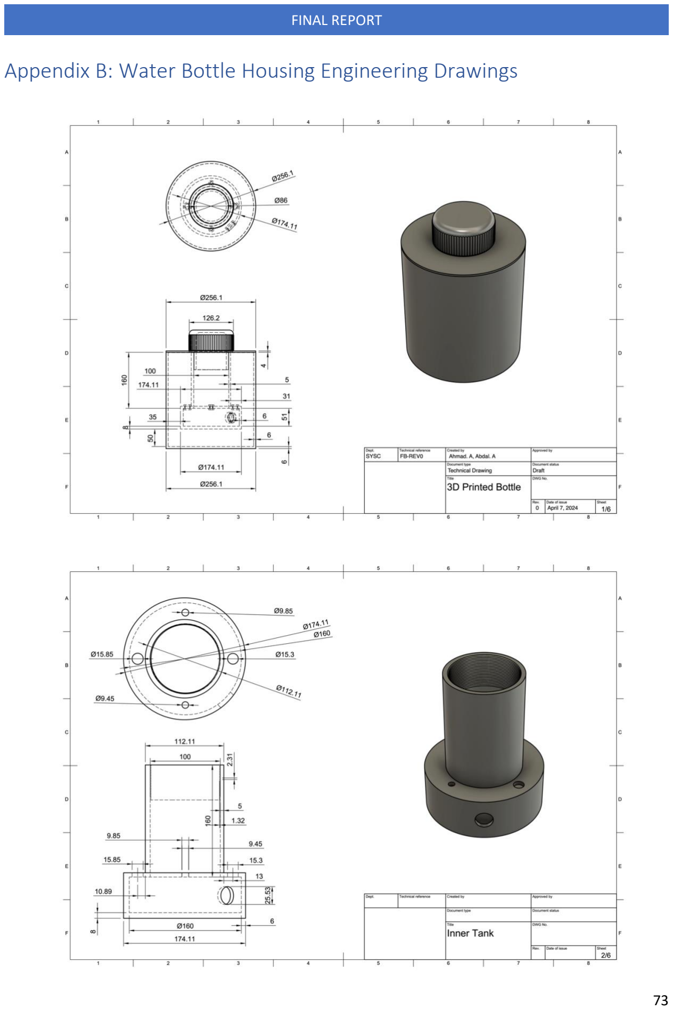
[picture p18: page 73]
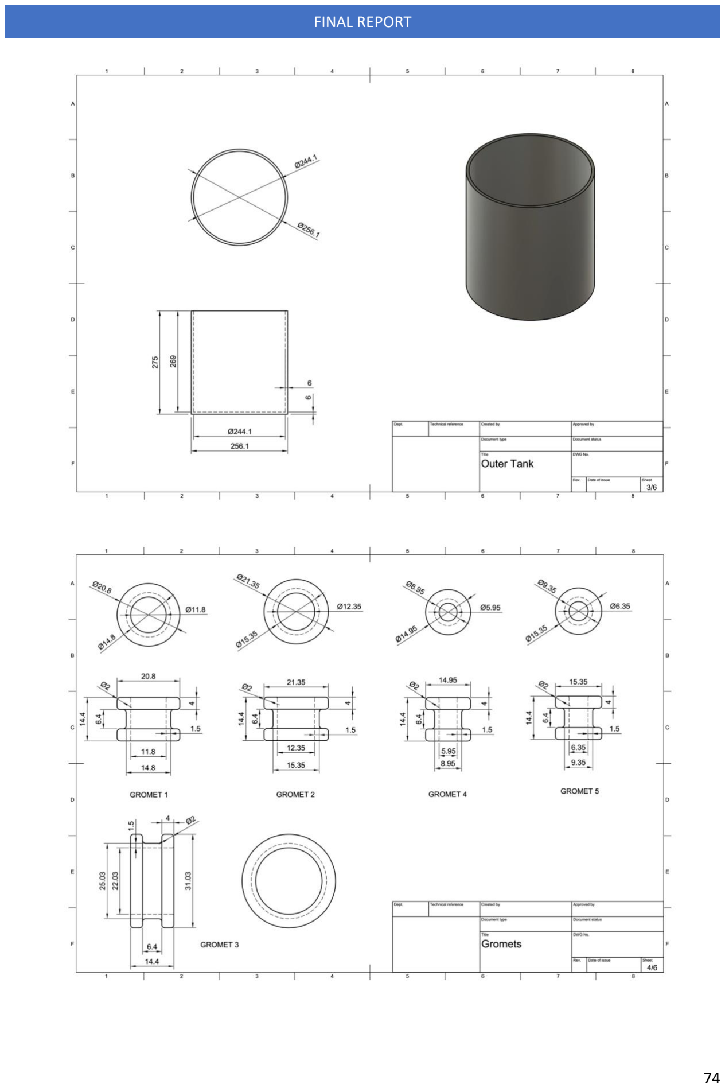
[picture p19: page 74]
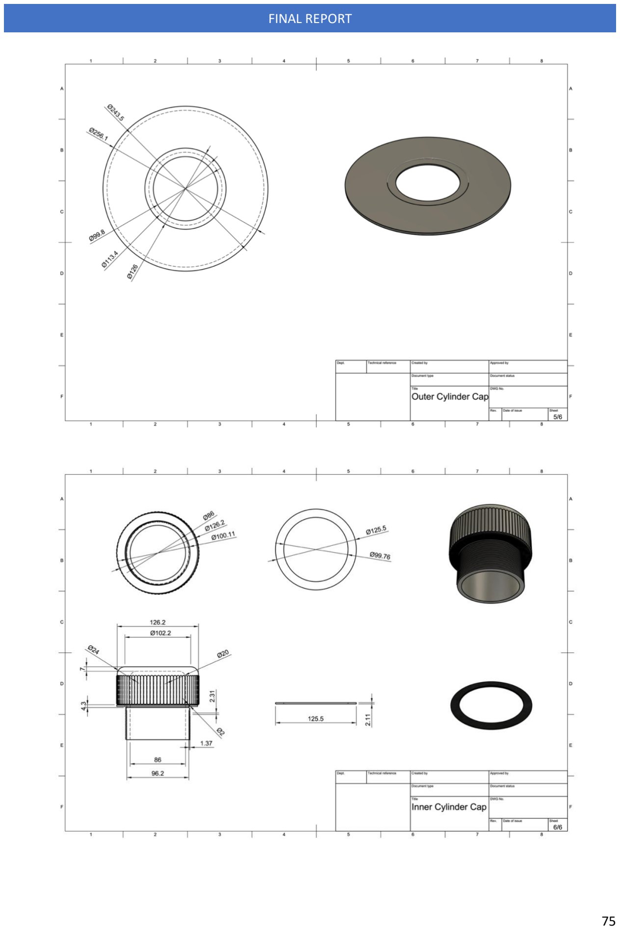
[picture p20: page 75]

## Appendix C: Project Progression Gantt Chart

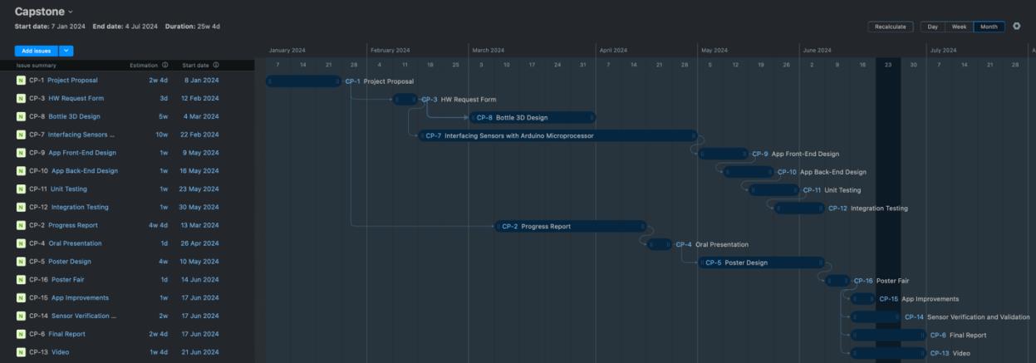
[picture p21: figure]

The Gantt chart above can also be viewed by following this link. (https://milestoneproject.youtrack.cloud/gantt-charts/186-0)

## Appendix D: List of Hardware Components Used

Part | Description | Link | Quantity | Price in CAD (tax inclusive)
Microcontroller | Arduino Uno R4 | Link (https://www.amazon.ca/Arduino-ABX00087-Official-Board-Italy/dp/B0C8V88Z9D) | 1 | $45
Power Supply | AsperX 10000mAh Power Bank | Link (https://www.amazon.ca/AsperX-10000mAh-Portable-External-iPhone14/dp/B0C88PM3LW?s=electronics) | 1 | $28
pH Sensor | Gravity Analog pH Sensor Kit | Link (https://www.dfrobot.com/product-1782.html) | 1 | $61
Turbidity Sensor | Gravity Analog Turbidity Sensor | Link (https://www.dfrobot.com/product-1394.html) | 1 | $15
TDS Sensors | Gravity Analog TDS Sensor | Link (https://www.dfrobot.com/product-1662.html) | 1 | $18
EC Sensor | Gravity Analog EC Sensor | Link (https://www.dfrobot.com/product-1123.html) | 1 | $107
Temperature Sensor | Gravity Digital Temperature Sensor | Link (https://www.dfrobot.com/product-1354.html) | 1 | $12

Breadboard | DfRobot Solderless Breadboard | Link (https://www.digikey.ca/en/products/detail/dfrobot/FIT0096/7597069) | 1 | $5
Jumper Wires | Male to Male Jumper Wires | Link (https://www.digikey.ca/en/products/detail/sparkfun-electronics/PRT-12795/5993860) | 1 pack (includes 20 pieces) | $4
Jumper Wires | Female to Male Jumper Wires | Link (https://www.digikey.ca/en/products/detail/sparkfun-electronics/PRT-12794/5993859) | 1 pack (includes 20 pieces) | $4
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

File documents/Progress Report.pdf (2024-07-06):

## HydraSmart

Ahmad Alkawasmeh, 101108706 (Software Engineering) Abdal Alkawasmeh, 101198752 (Software Engineering) Supervisor: Prof. Safaa Bedawi

Abstract
Have you ever thought of how clean the water you drink? Do you have to constantly drink bottled water? Are you tired of second guessing if you should drink tap water? water quality has been an immersing issue over the years and water quality systems have been more in demand.

In this project development, we will be able to implement an automated water quality system which will be allow users to remotely test the quality of a water sample. Using a few metrics, the system will provide the user with water quality readings and determine if the water is safe to drink by displaying a message to the user. By using this product, the user will also be able to carry and sample any water from anywhere.

This product will ensure the user consumes safe and drinking water and is quite useful to anyone. However, it may be more beneficial for those travelling or don’t have access to filtered water. For example,teachers may wish to check the water quality on a field trip before children start to consume it. Therefore, by conducting a simple water test, it ensures the safety of the water.

Capstone Project Progress Report, 2024

## Contents

1 Introduction | 3
2 Professional Considerations | 5
3 Theory and Techniques | 8
4 Results and Discussions | 10
5 Conclusion | 15

## 1 Introduction

### 1.1 Overview and Background

We go about our everyday life without giving much thought to the quality of water we consume on a daily basis. Especially that we need to intake about 3.7 Litres of water per day [1] to maintain healthy body functions, therefore we must pay close attention to the quality of the water we consume. Currently, the most widely used technique of determining the quality of the water is by using Test Strips. Which are rectangular pieces of paper that are saturated with a chemical agent, once these paper strips are submerged in a water sample, the chemical agent will react with the water and change colour. Then this colour will indicate the test result, which then the user will need to match the colour produced by the paper strip to a result chart with all the possible colours that can be produced by the test strip and what they indicate. This method of testing the water quality is not accurate and cannot provide exact quantitated results.
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

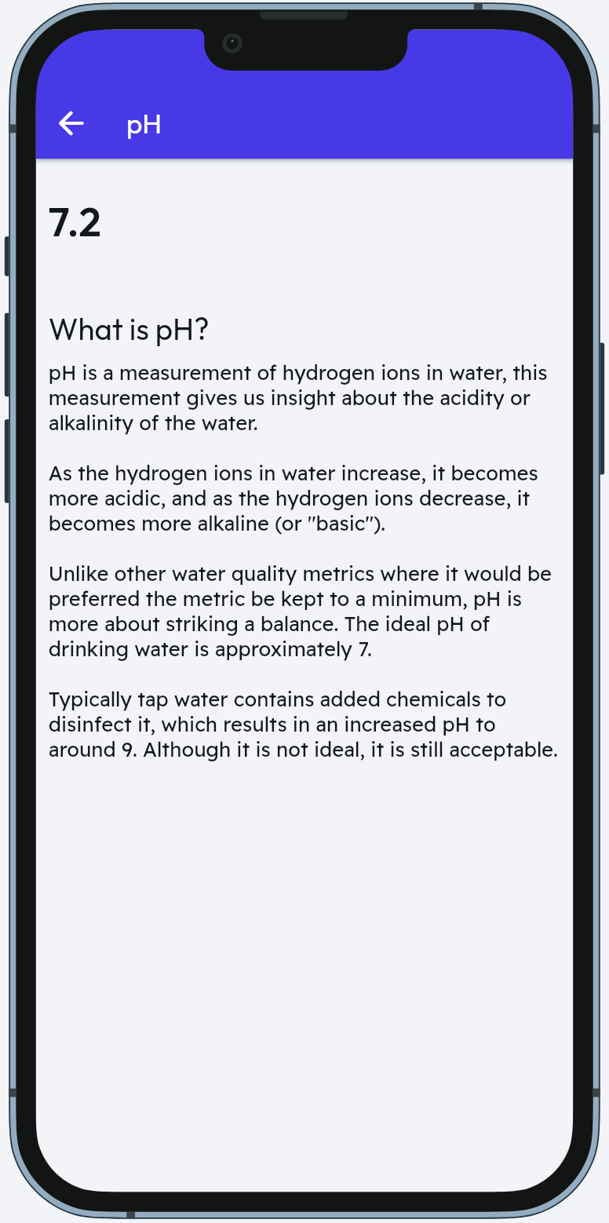
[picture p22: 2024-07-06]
application preview/phPage.png

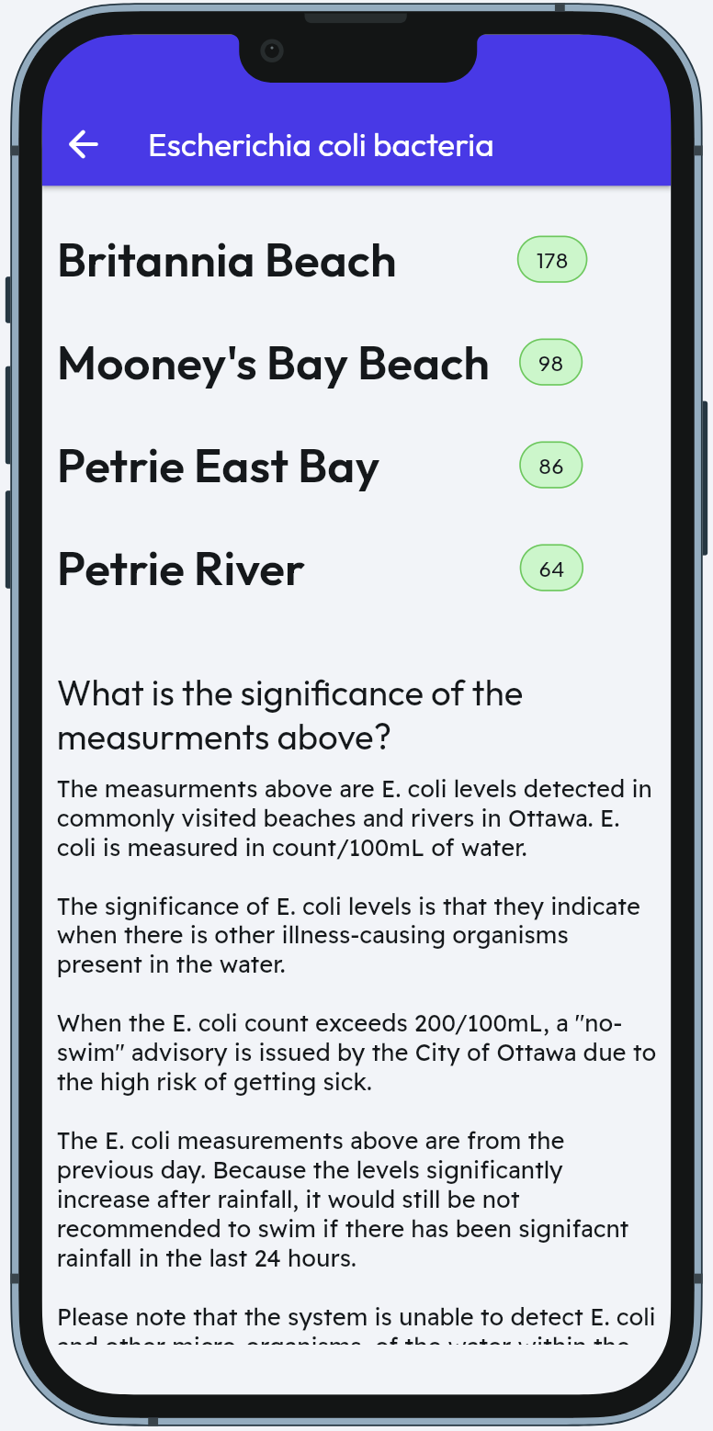
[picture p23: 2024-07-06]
application preview/ecoliPage.png

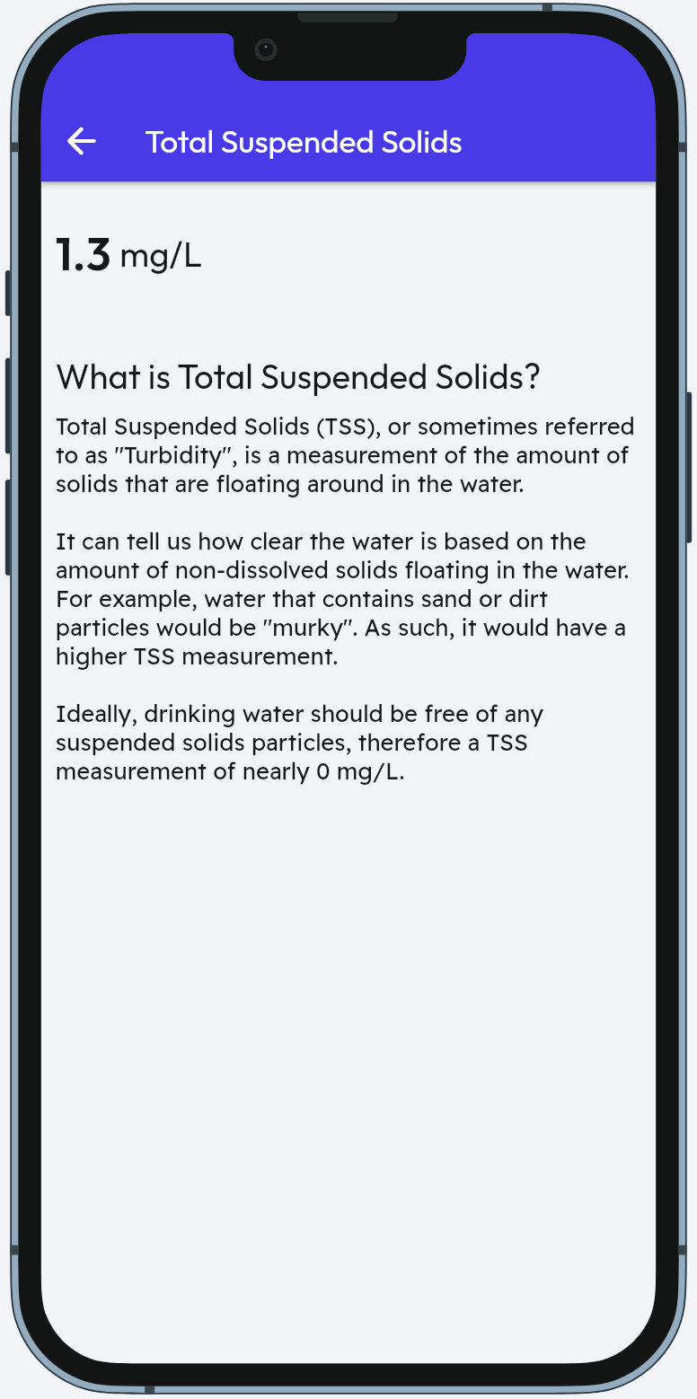
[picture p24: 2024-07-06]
application preview/tssPage.png

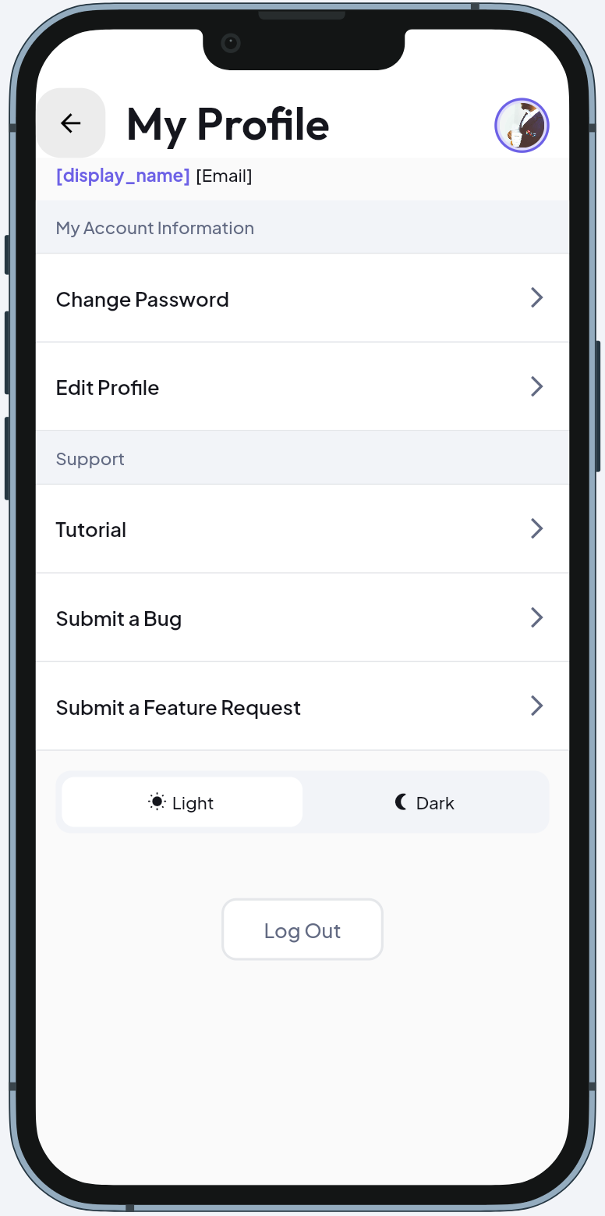
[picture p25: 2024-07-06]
application preview/settingsPage.png

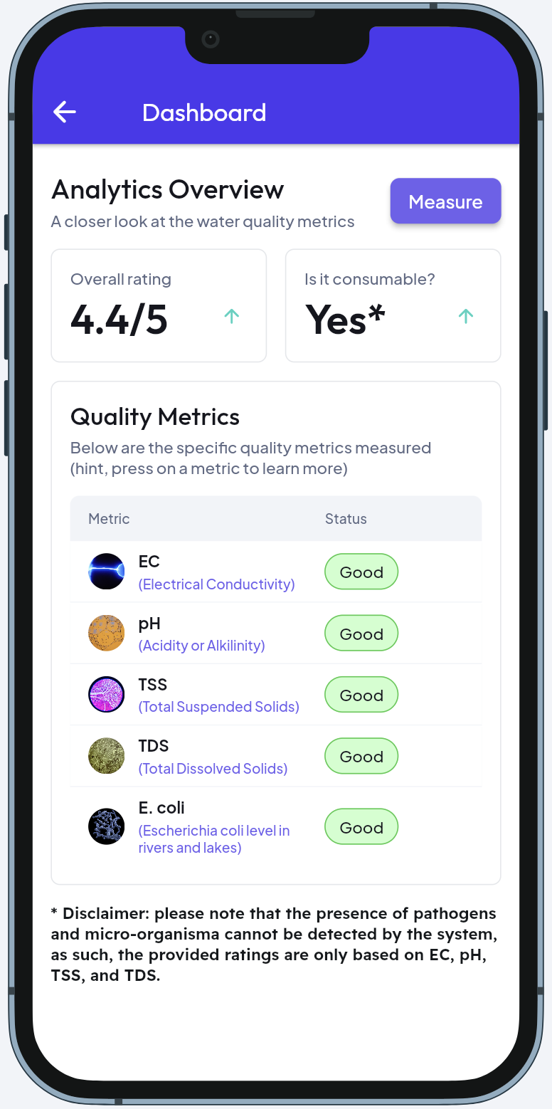
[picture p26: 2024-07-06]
application preview/dashboardPage.png

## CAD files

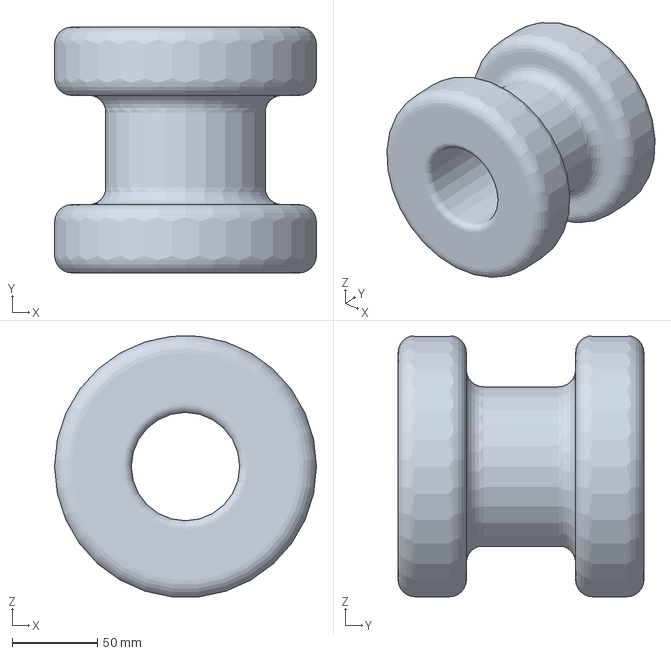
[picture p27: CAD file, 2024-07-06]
3D bottle design/Parts 3mf/ECOR4907-AhmadAlkawasmeh-Grommet5-TPU-Apr-7-2024.3mf
153.5 x 144.0 x 152.7 mm

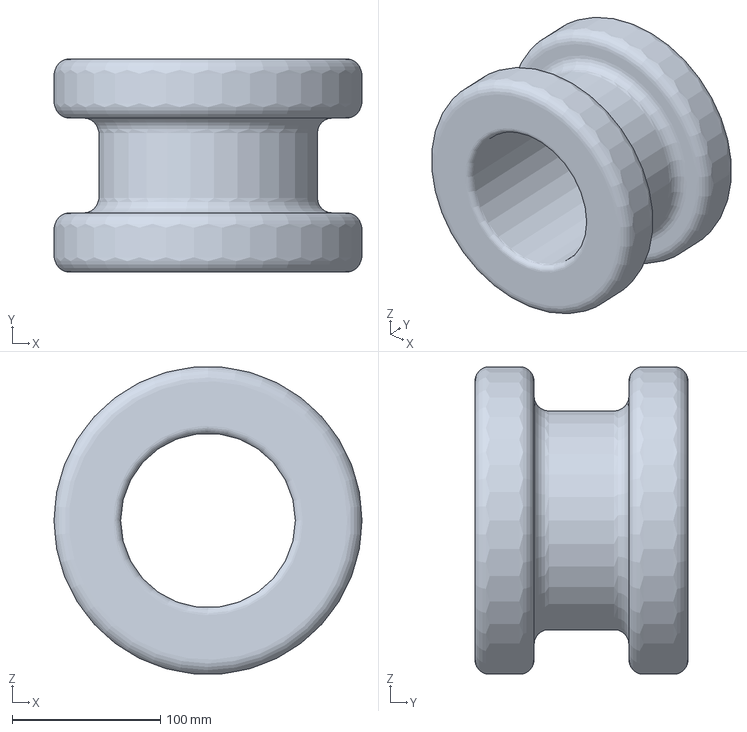
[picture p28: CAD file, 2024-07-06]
3D bottle design/Parts 3mf/ECOR4907-AhmadAlkawasmeh-Grommet1-TPU-Apr-7-2024.3mf
208.0 x 144.0 x 207.3 mm

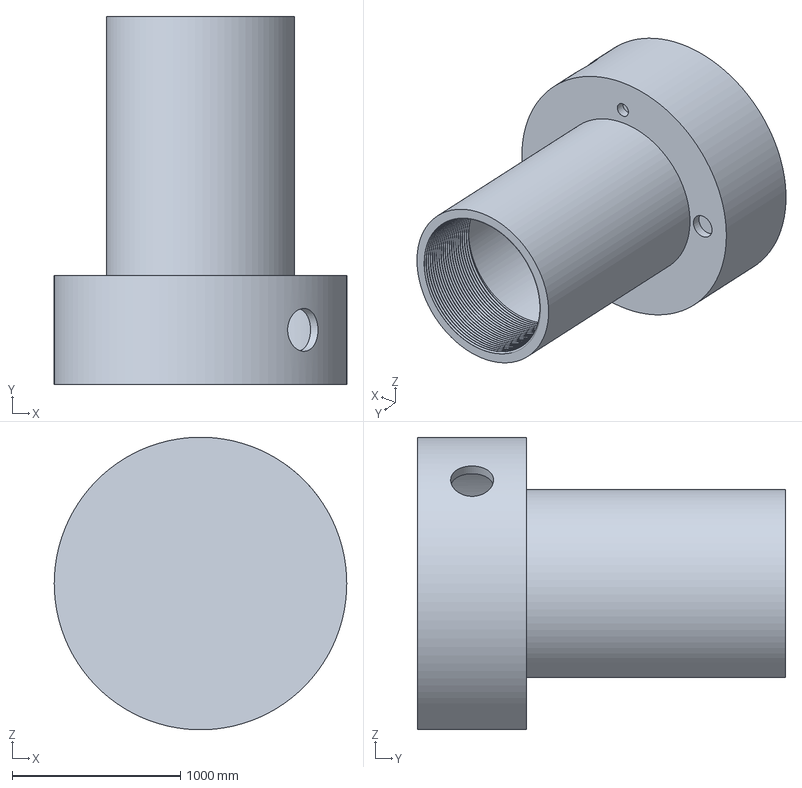
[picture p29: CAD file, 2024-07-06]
3D bottle design/Parts 3mf/ECOR4907-AhmadAlkawasmeh-InnerCylinder-PLA-Apr-7-2024.3mf
1741.1 x 2190.0 x 1740.2 mm

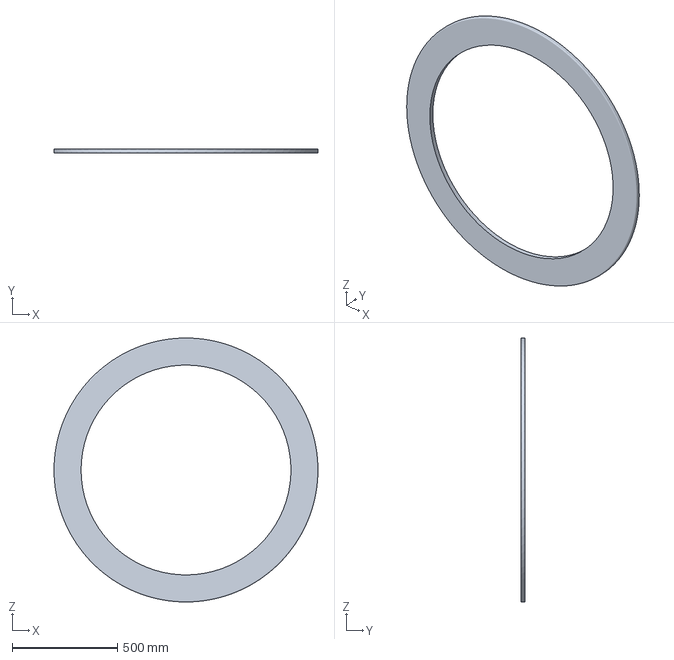
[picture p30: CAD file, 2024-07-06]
3D bottle design/Parts 3mf/ECOR4907-AhmadAlkawasmeh-Grommet6-TPU-Apr-7-2024.3mf
1255.0 x 21.1 x 1255.0 mm

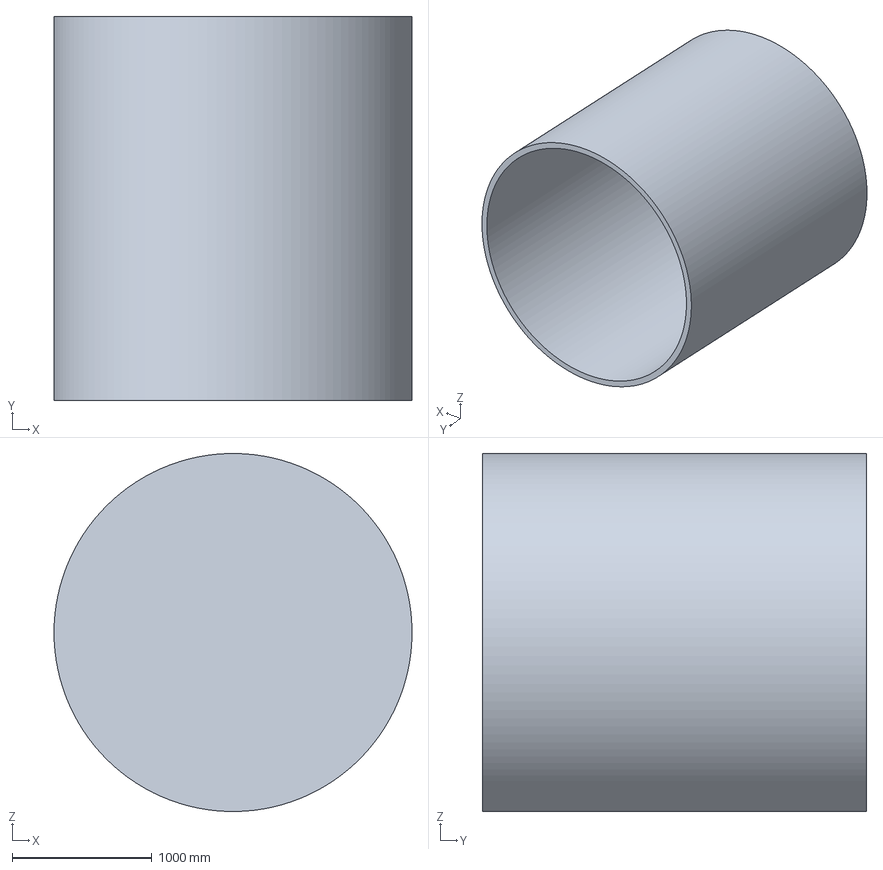
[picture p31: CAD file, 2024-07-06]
3D bottle design/Parts 3mf/ECOR4907-AhmadAlkawasmeh-OuterCylinder-PLA-Apr-7-2024.3mf
2560.6 x 2750.0 x 2560.8 mm

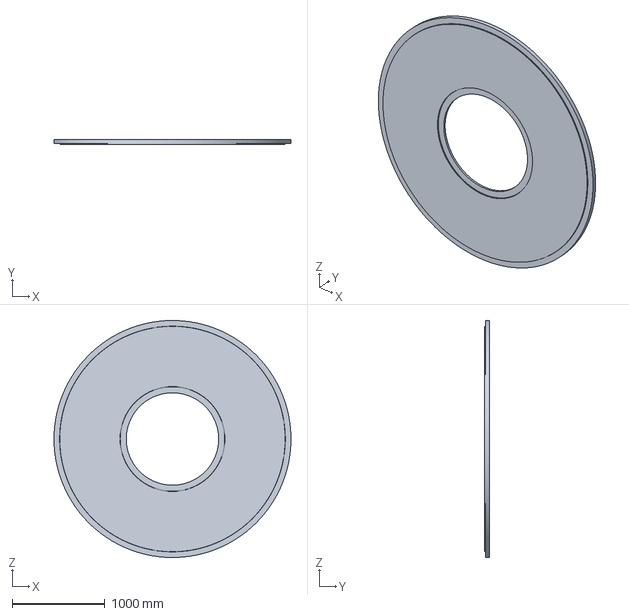
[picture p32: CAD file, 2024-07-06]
3D bottle design/Parts 3mf/ECOR4907-AhmadAlkawasmeh-OuterCap-PLA-Apr-7-2024.3mf
2560.6 x 50.0 x 2560.8 mm

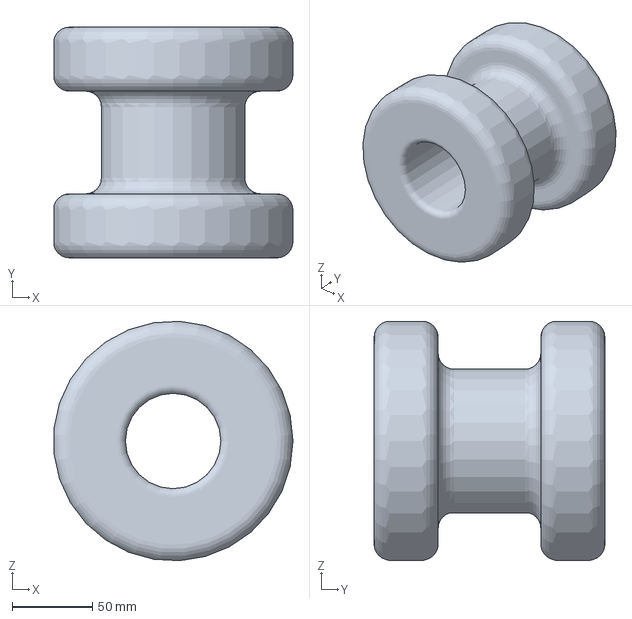
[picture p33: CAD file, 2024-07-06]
3D bottle design/Parts 3mf/ECOR4907-AhmadAlkawasmeh-Grommet4-TPU-Apr-7-2024.3mf
149.1 x 144.0 x 149.3 mm

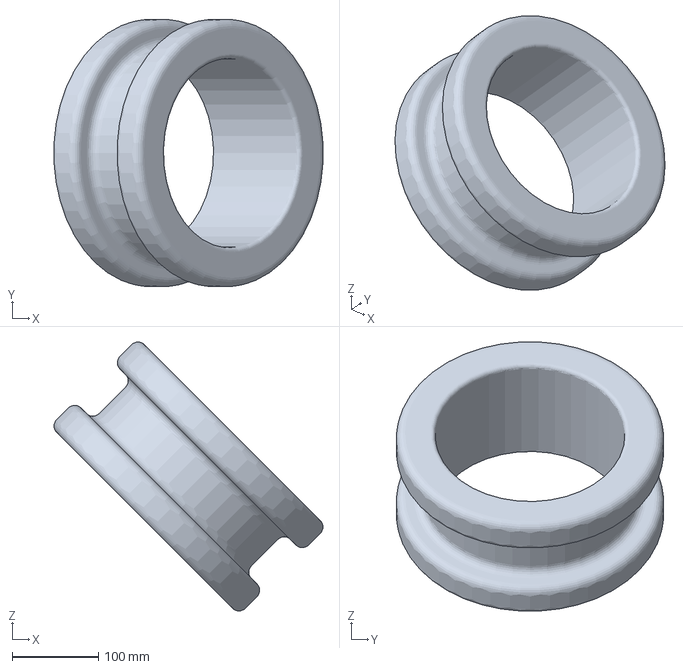
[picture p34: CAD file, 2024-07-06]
3D bottle design/Parts 3mf/ECOR4907-AhmadAlkawasmeh-Grommet3-TPU-Apr-7-2024.3mf
312.4 x 309.6 x 312.4 mm

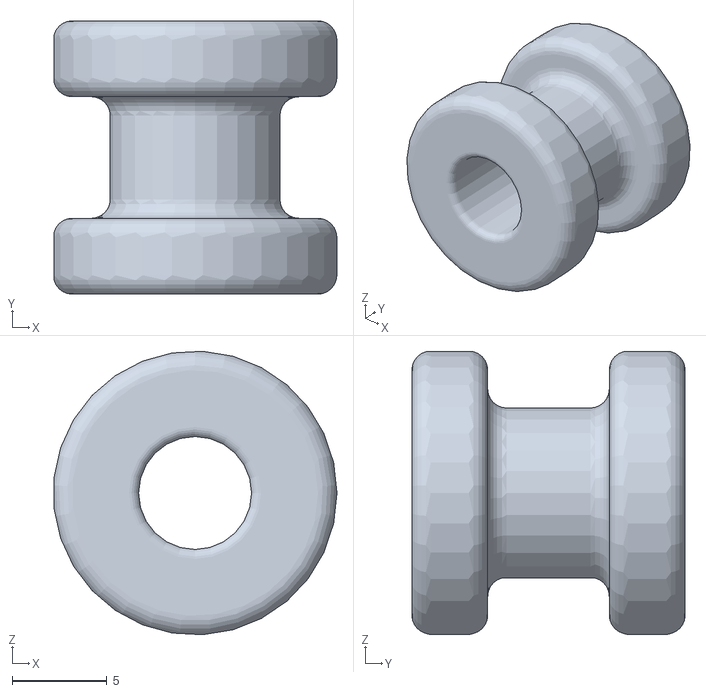
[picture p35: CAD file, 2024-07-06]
3D bottle design/Parts STL/Grommet-4-TPU.stl
14.9 x 14.4 x 14.9

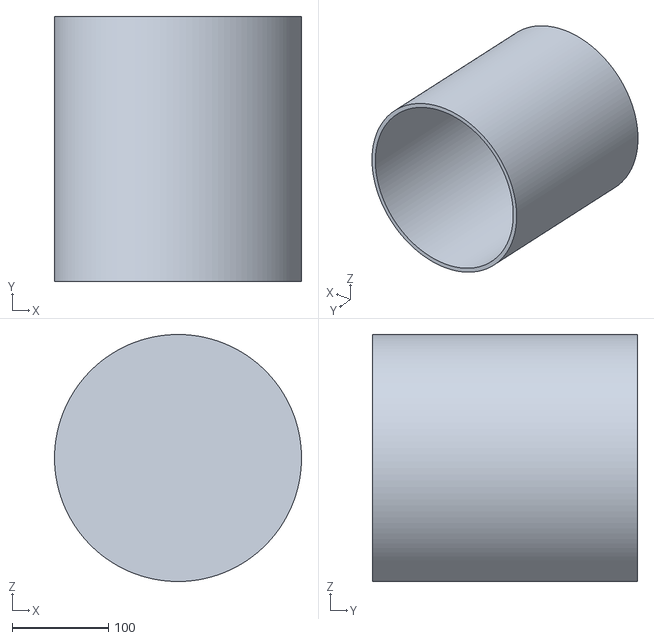
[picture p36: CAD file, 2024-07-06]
3D bottle design/Parts STL/OuterCylinder-PLA.stl
256.1 x 275.0 x 256.1

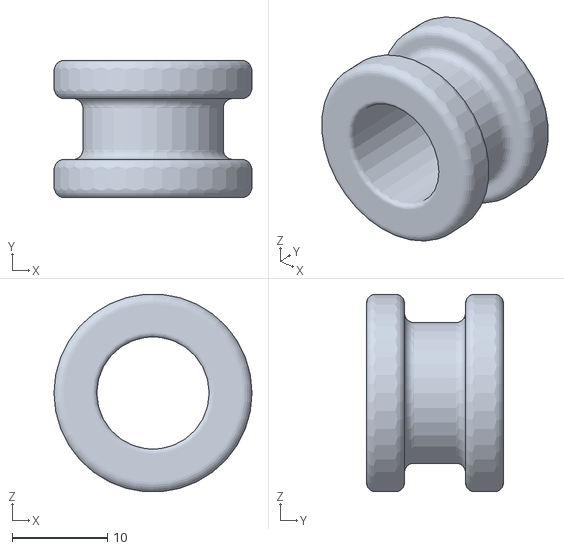
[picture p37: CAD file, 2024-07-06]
3D bottle design/Parts STL/Grommet-1-TPU.stl
20.8 x 14.4 x 20.7

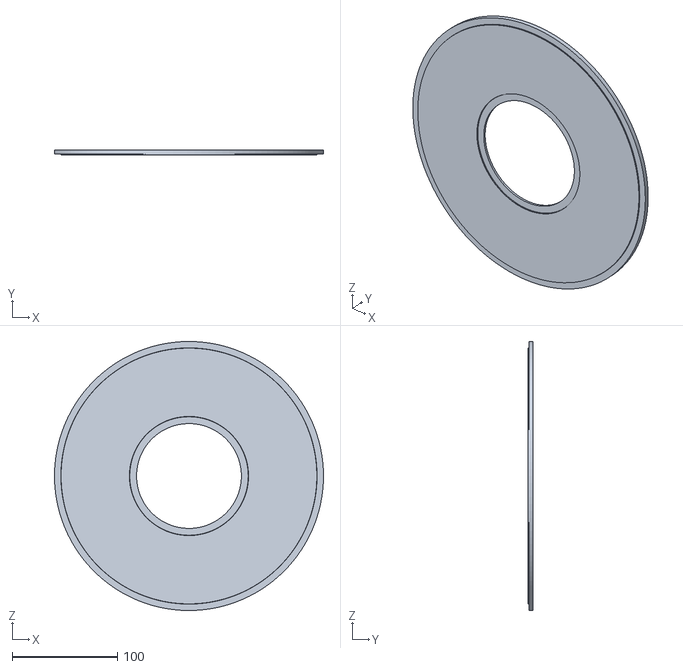
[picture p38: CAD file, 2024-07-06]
3D bottle design/Parts STL/OuterCylinderCap-PLA.stl
256.1 x 5.00 x 256.1

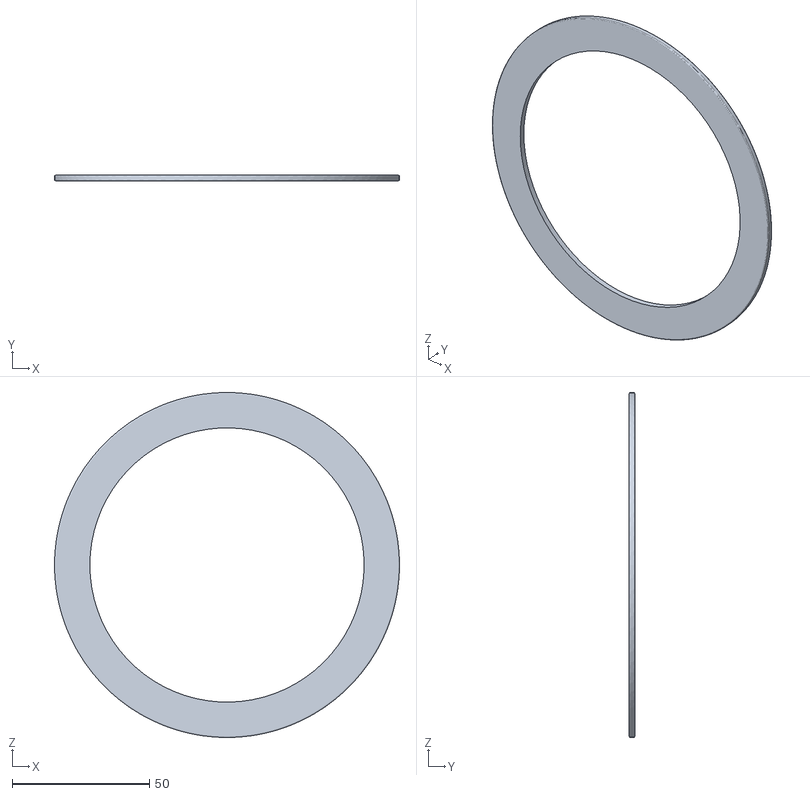
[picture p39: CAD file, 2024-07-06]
3D bottle design/Parts STL/InnerCapSeal-TPU.stl
125.5 x 2.11 x 125.5

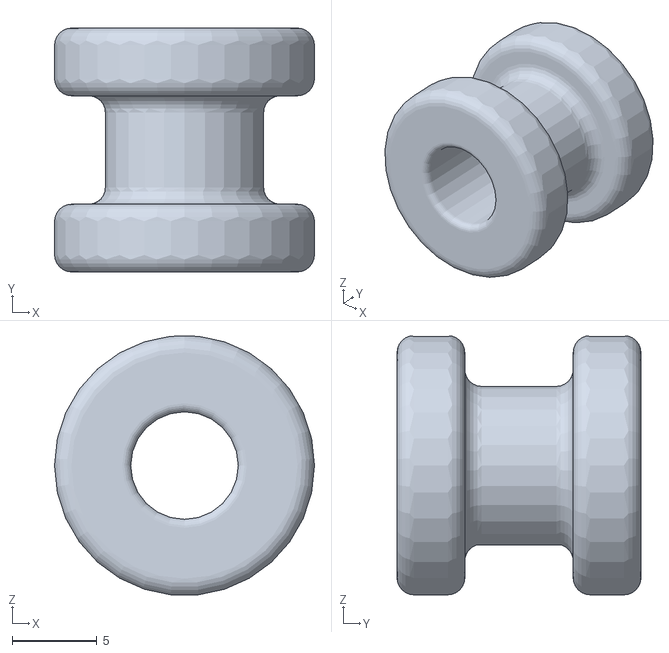
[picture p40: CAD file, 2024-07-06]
3D bottle design/Parts STL/Grommet-5-TPU.stl
15.3 x 14.4 x 15.3

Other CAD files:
3D bottle design/Parts STL/Grommet-3-TPU.stl
3D bottle design/Parts STL/Grommet-2-TPU.stl

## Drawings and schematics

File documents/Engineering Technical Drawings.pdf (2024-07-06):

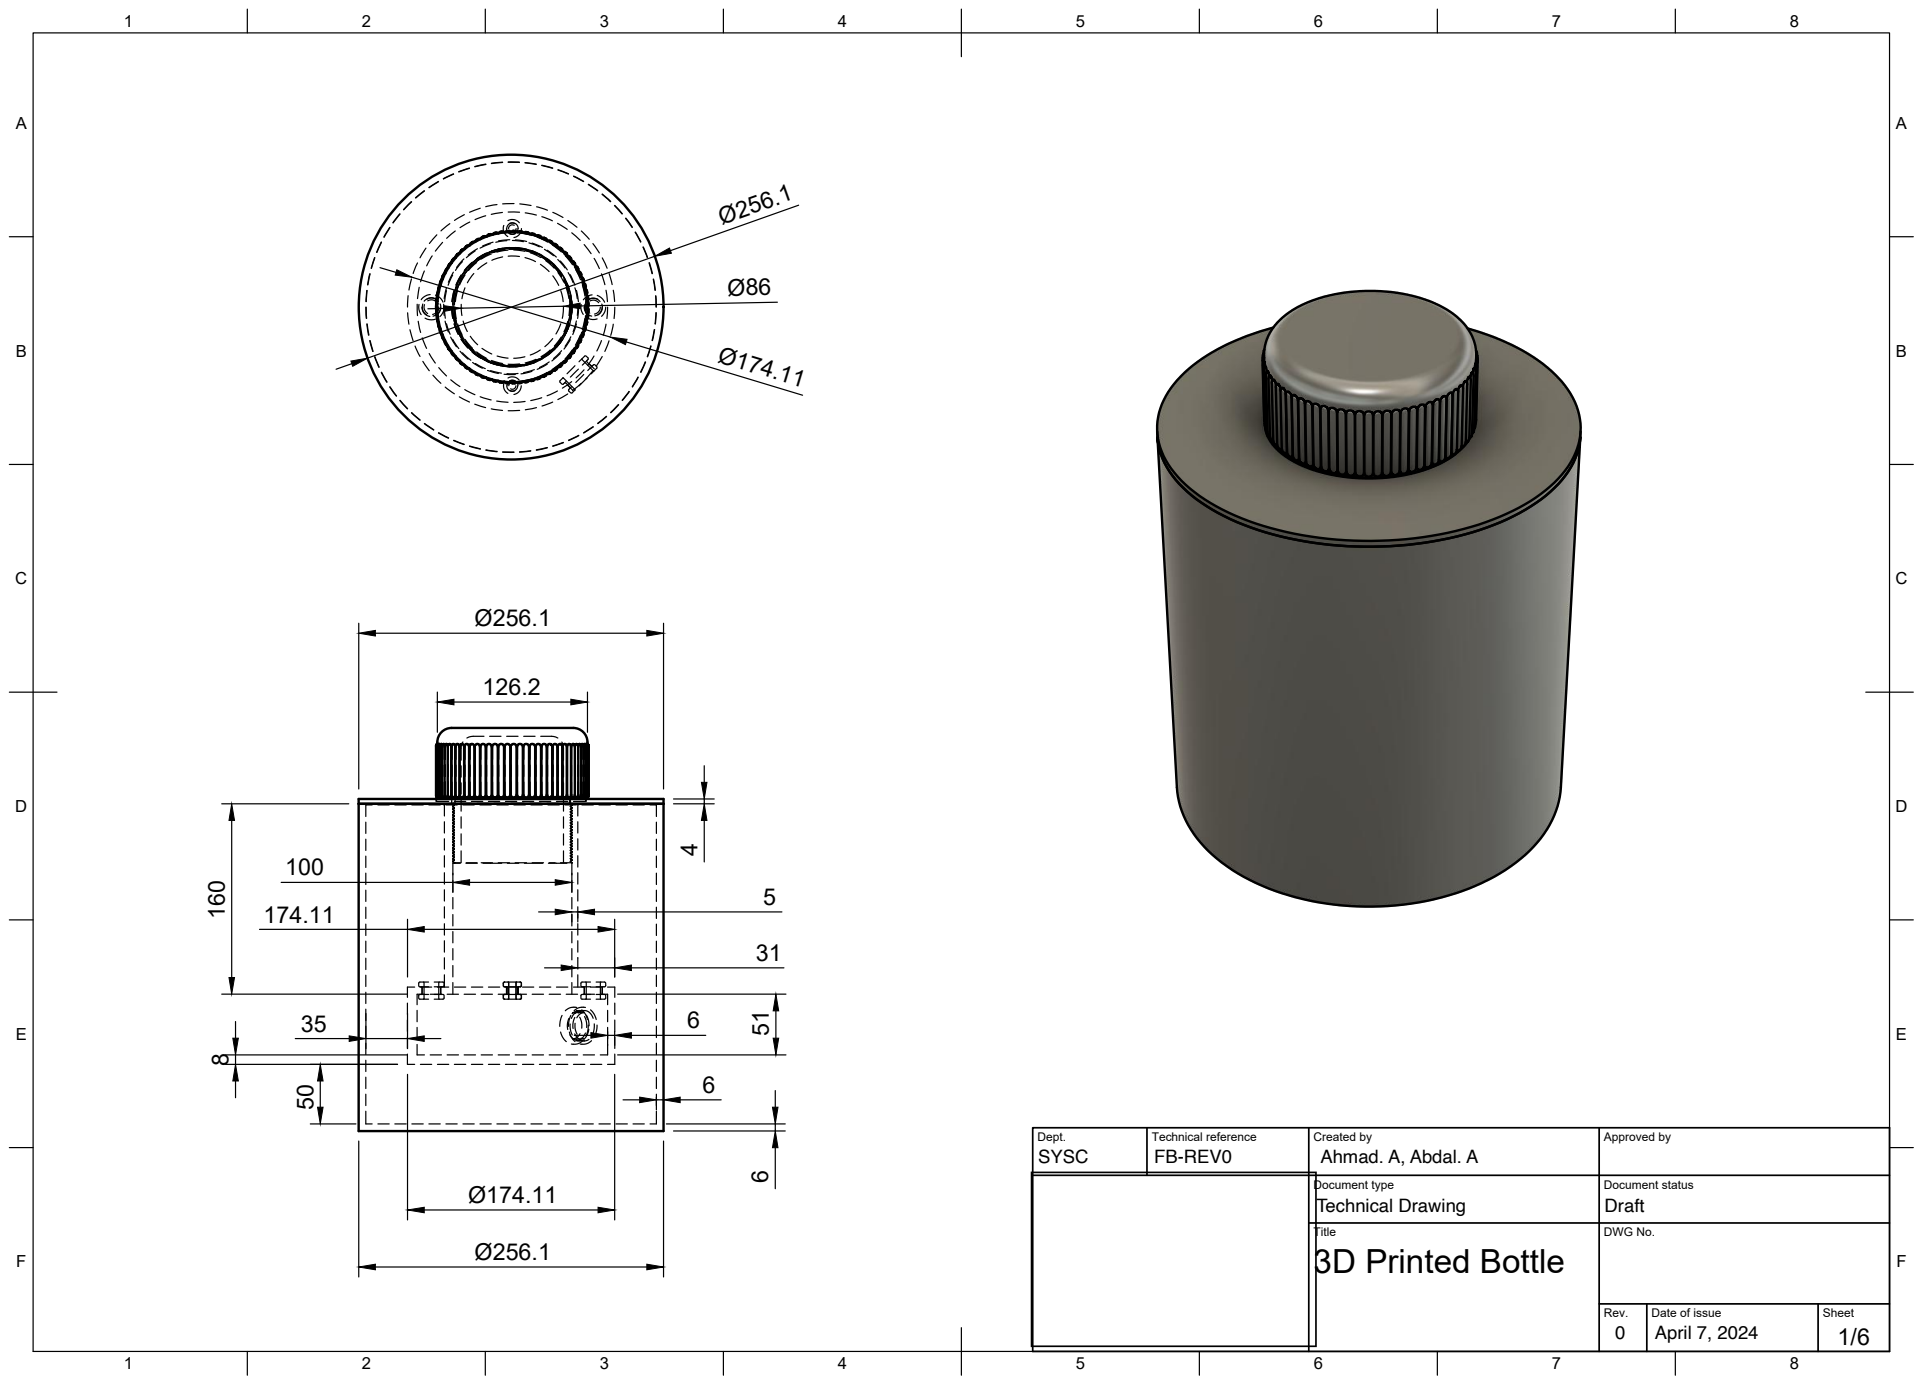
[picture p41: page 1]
Title; DWG No.; Rev.; Date of issue; Sheet; 3D Printed Bottle

Dept. | Technical reference | Created by | Approved by

Document type | Document status

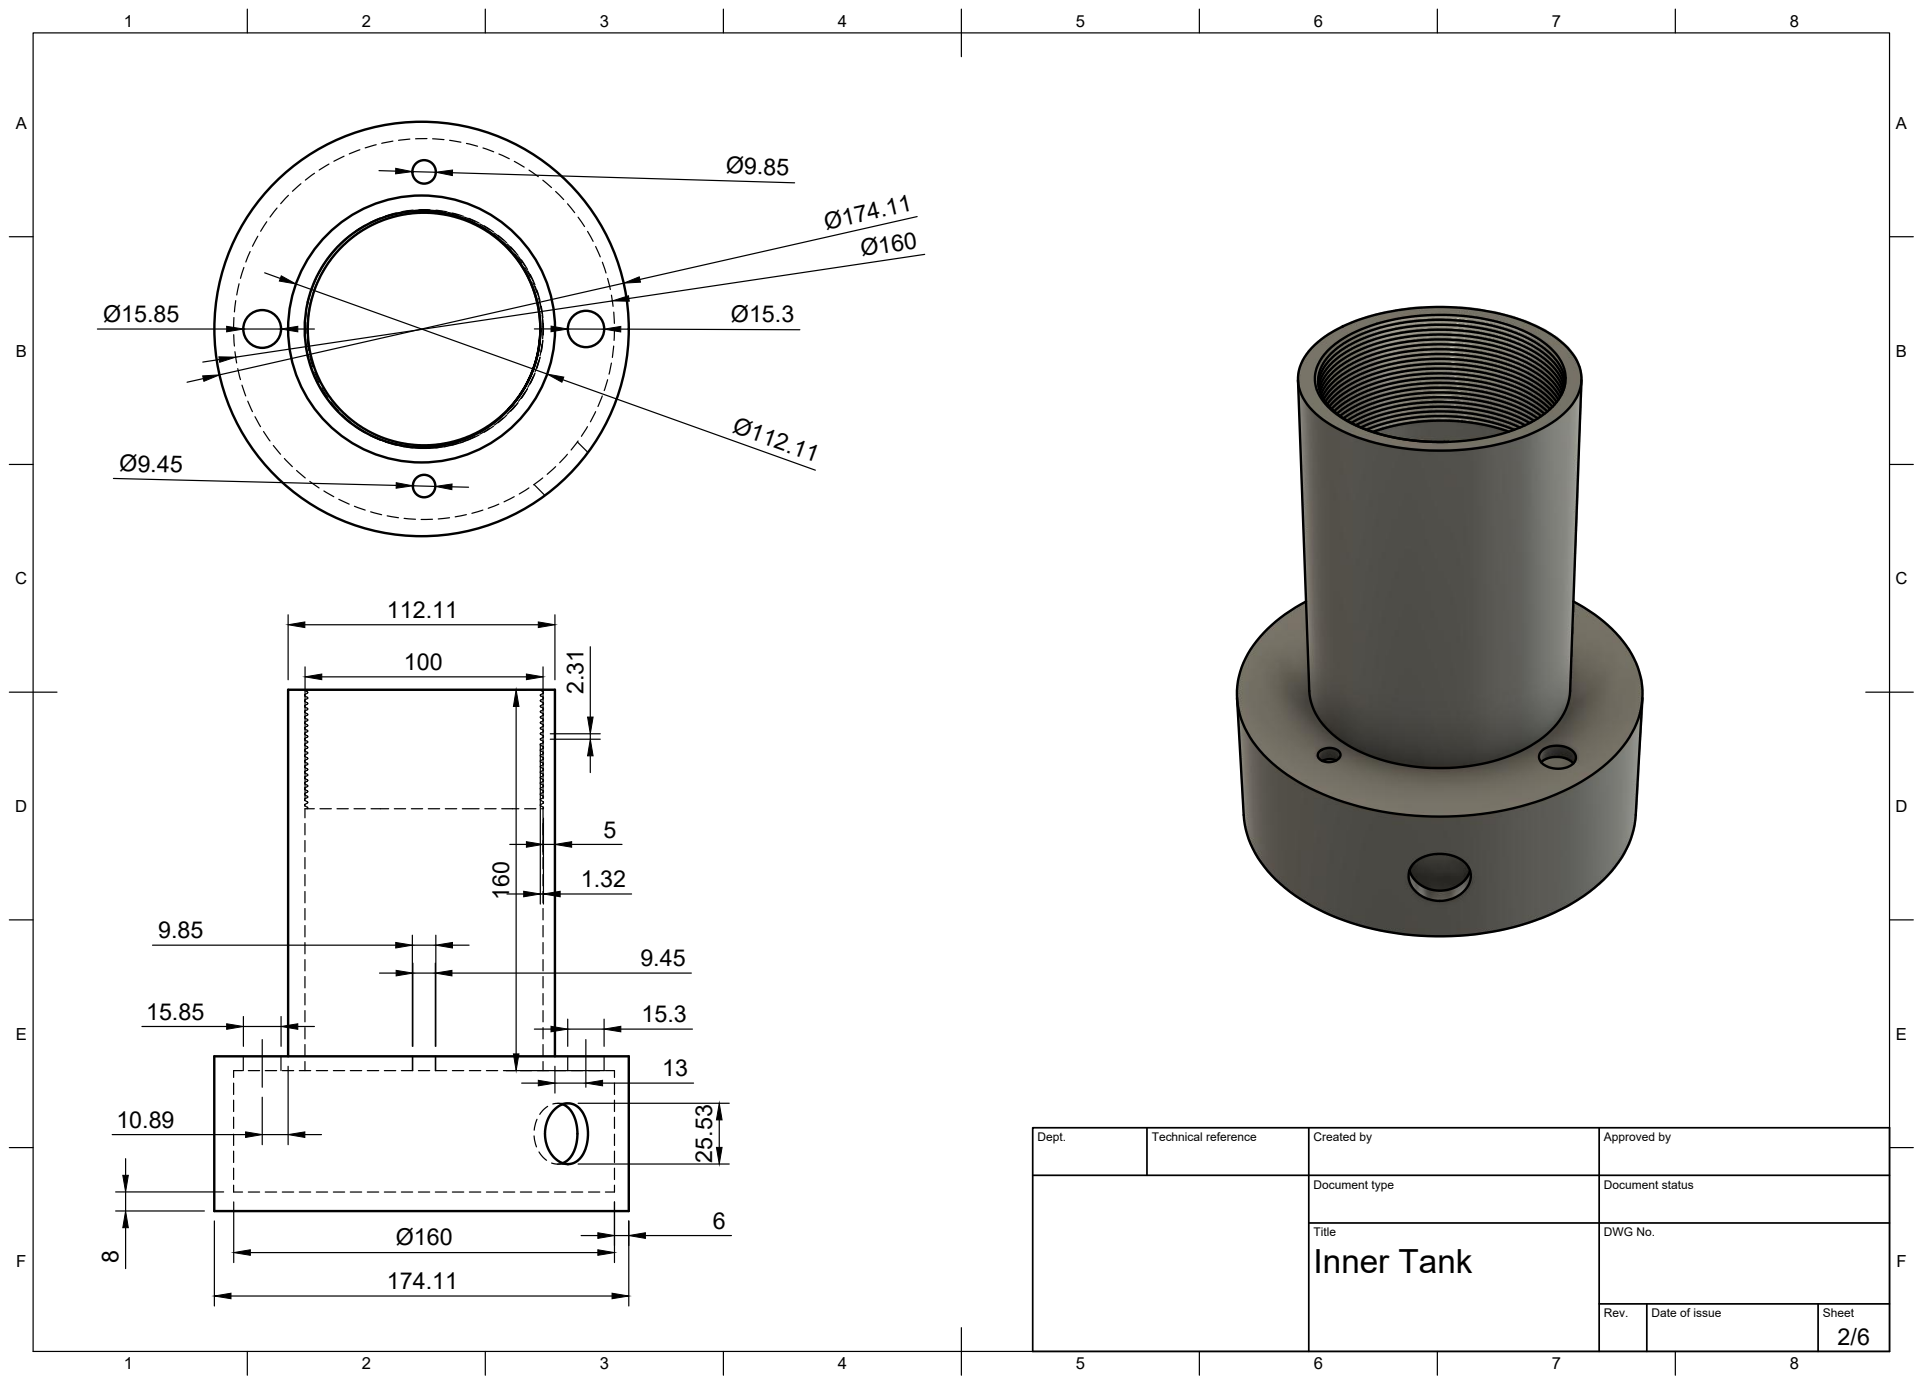
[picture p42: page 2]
Title; DWG No.; Inner Tank 2.31

Dept. | Technical reference | Created by | Approved by

Document type | Document status

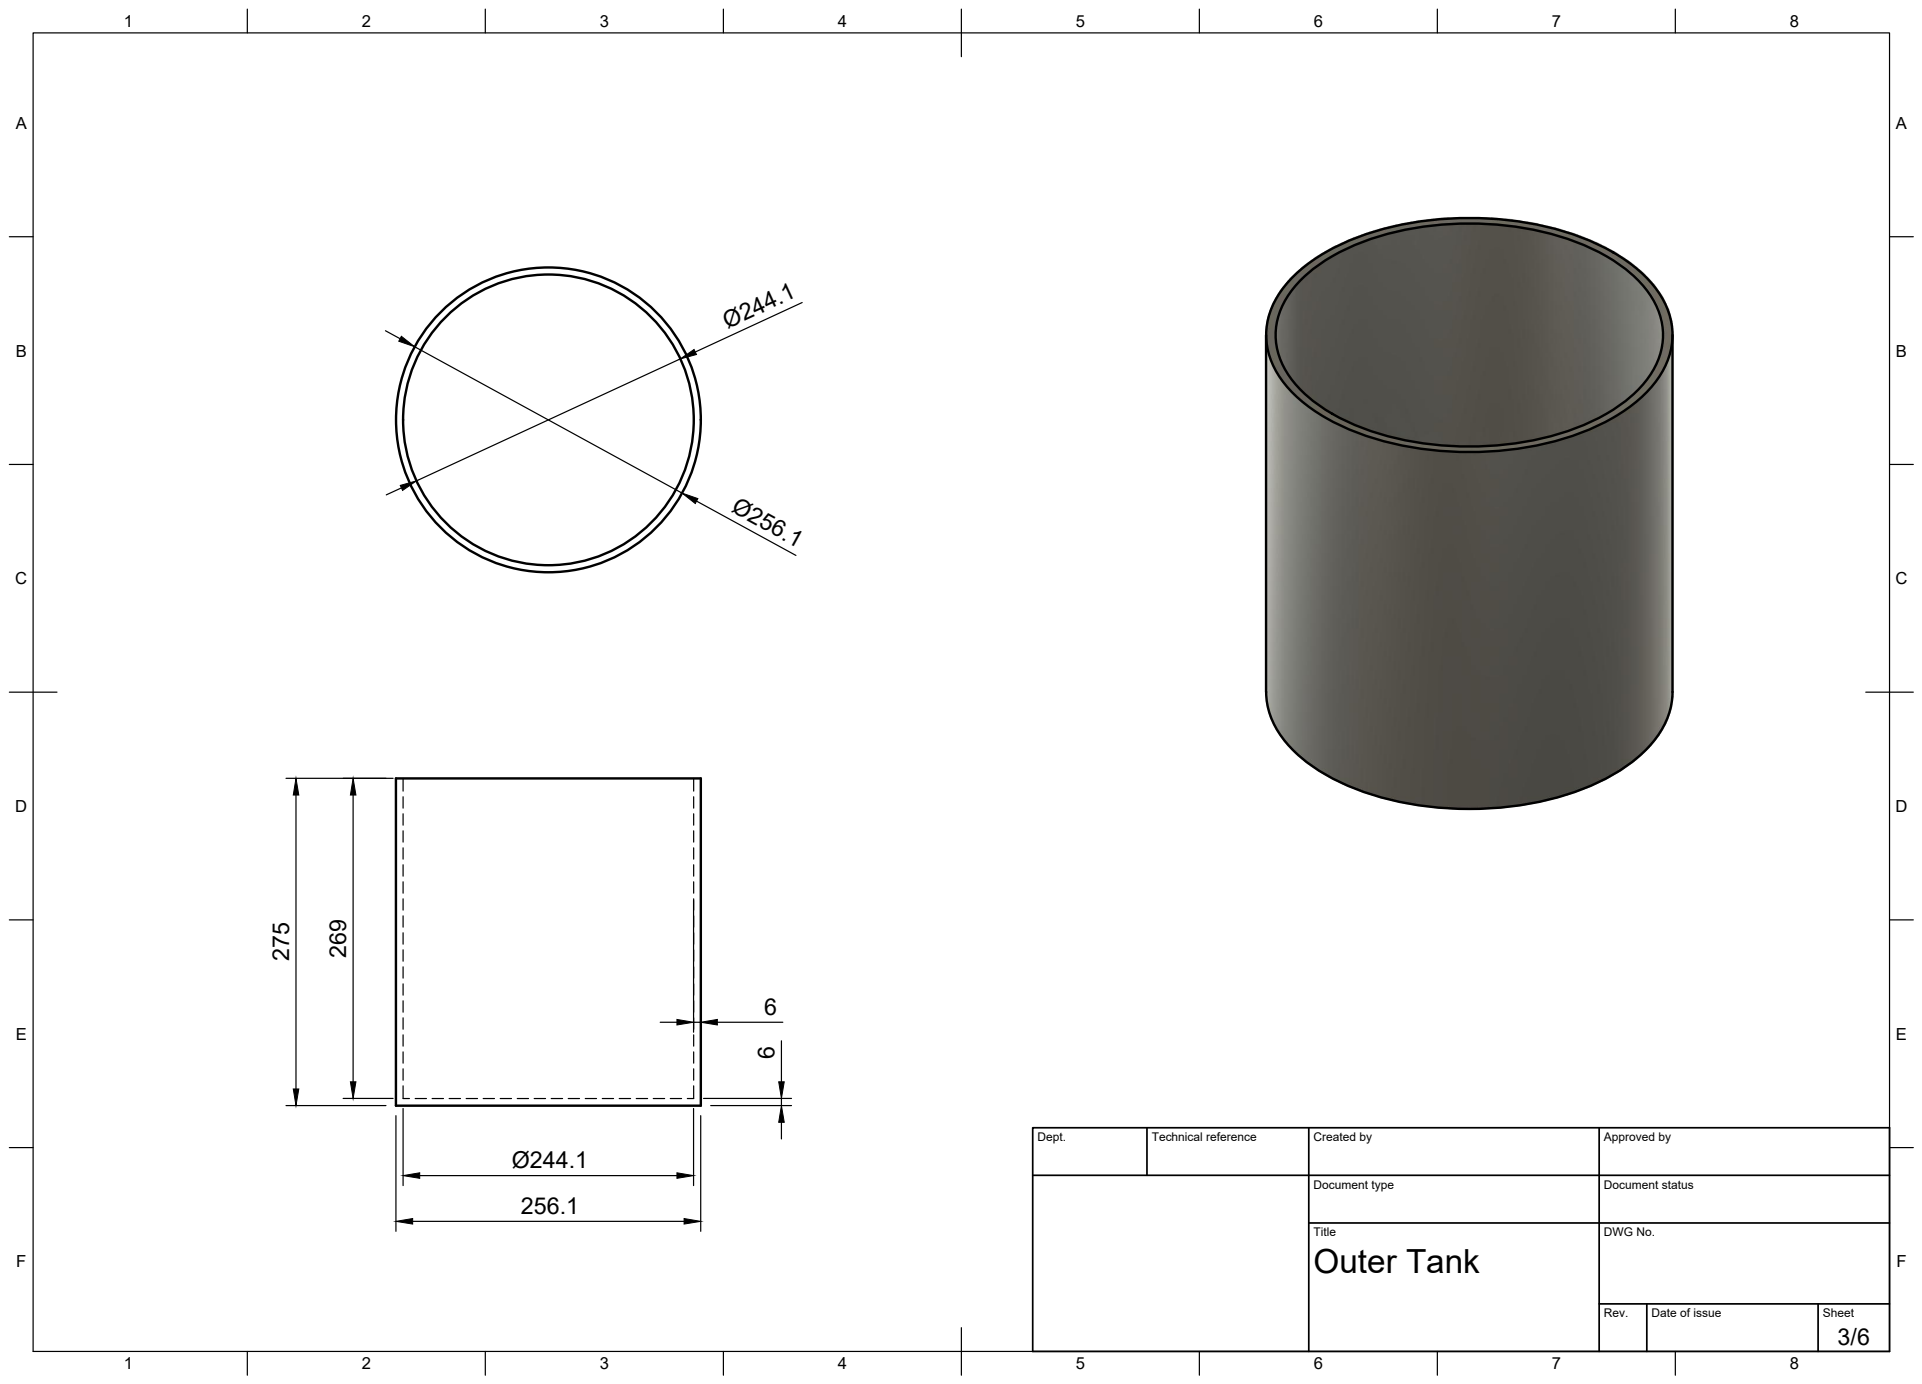
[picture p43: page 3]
Title; DWG No.; Outer Tank

Dept. | Technical reference | Created by | Approved by

Document type | Document status

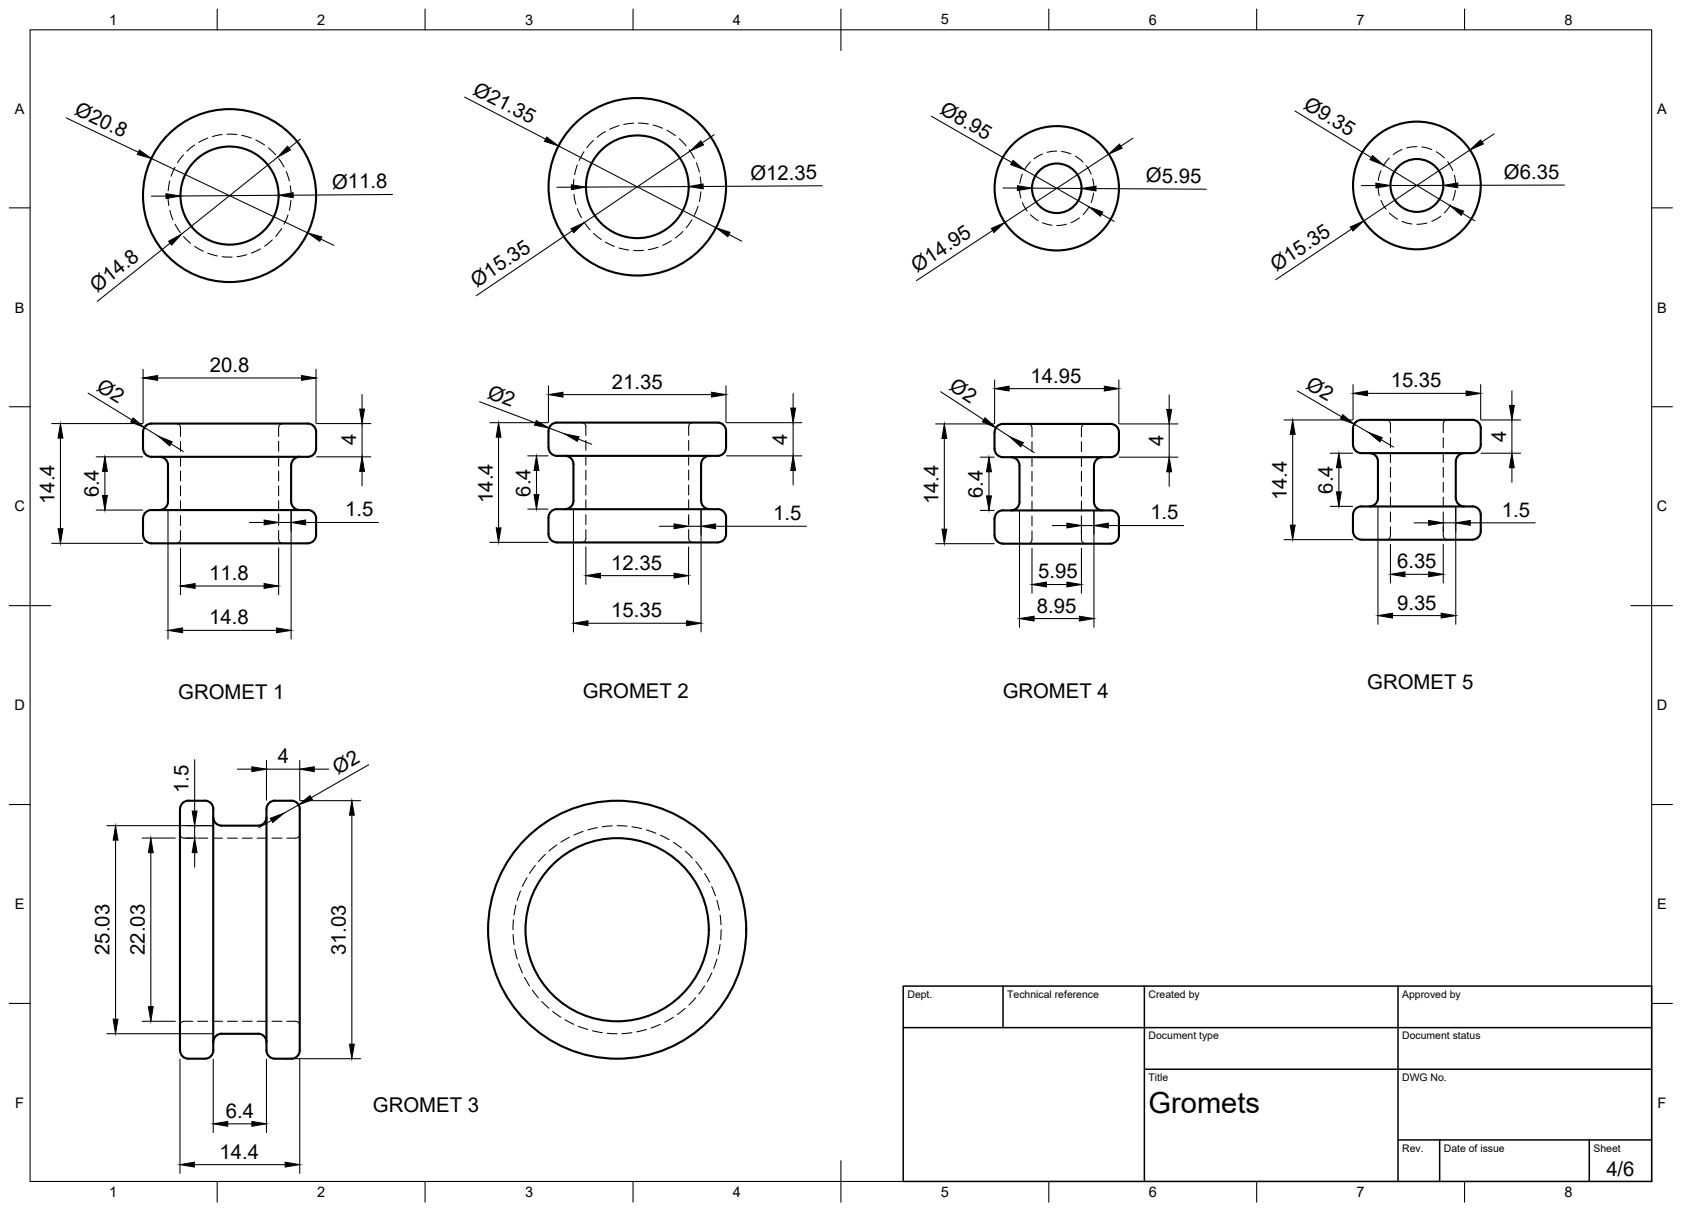
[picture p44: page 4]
Title; DWG No.; GROMET 1; GROMET 2; GROMET 4; GROMET 5; GROMET 3 25.03

Dept. | Technical reference | Created by | Approved by

Document type | Document status

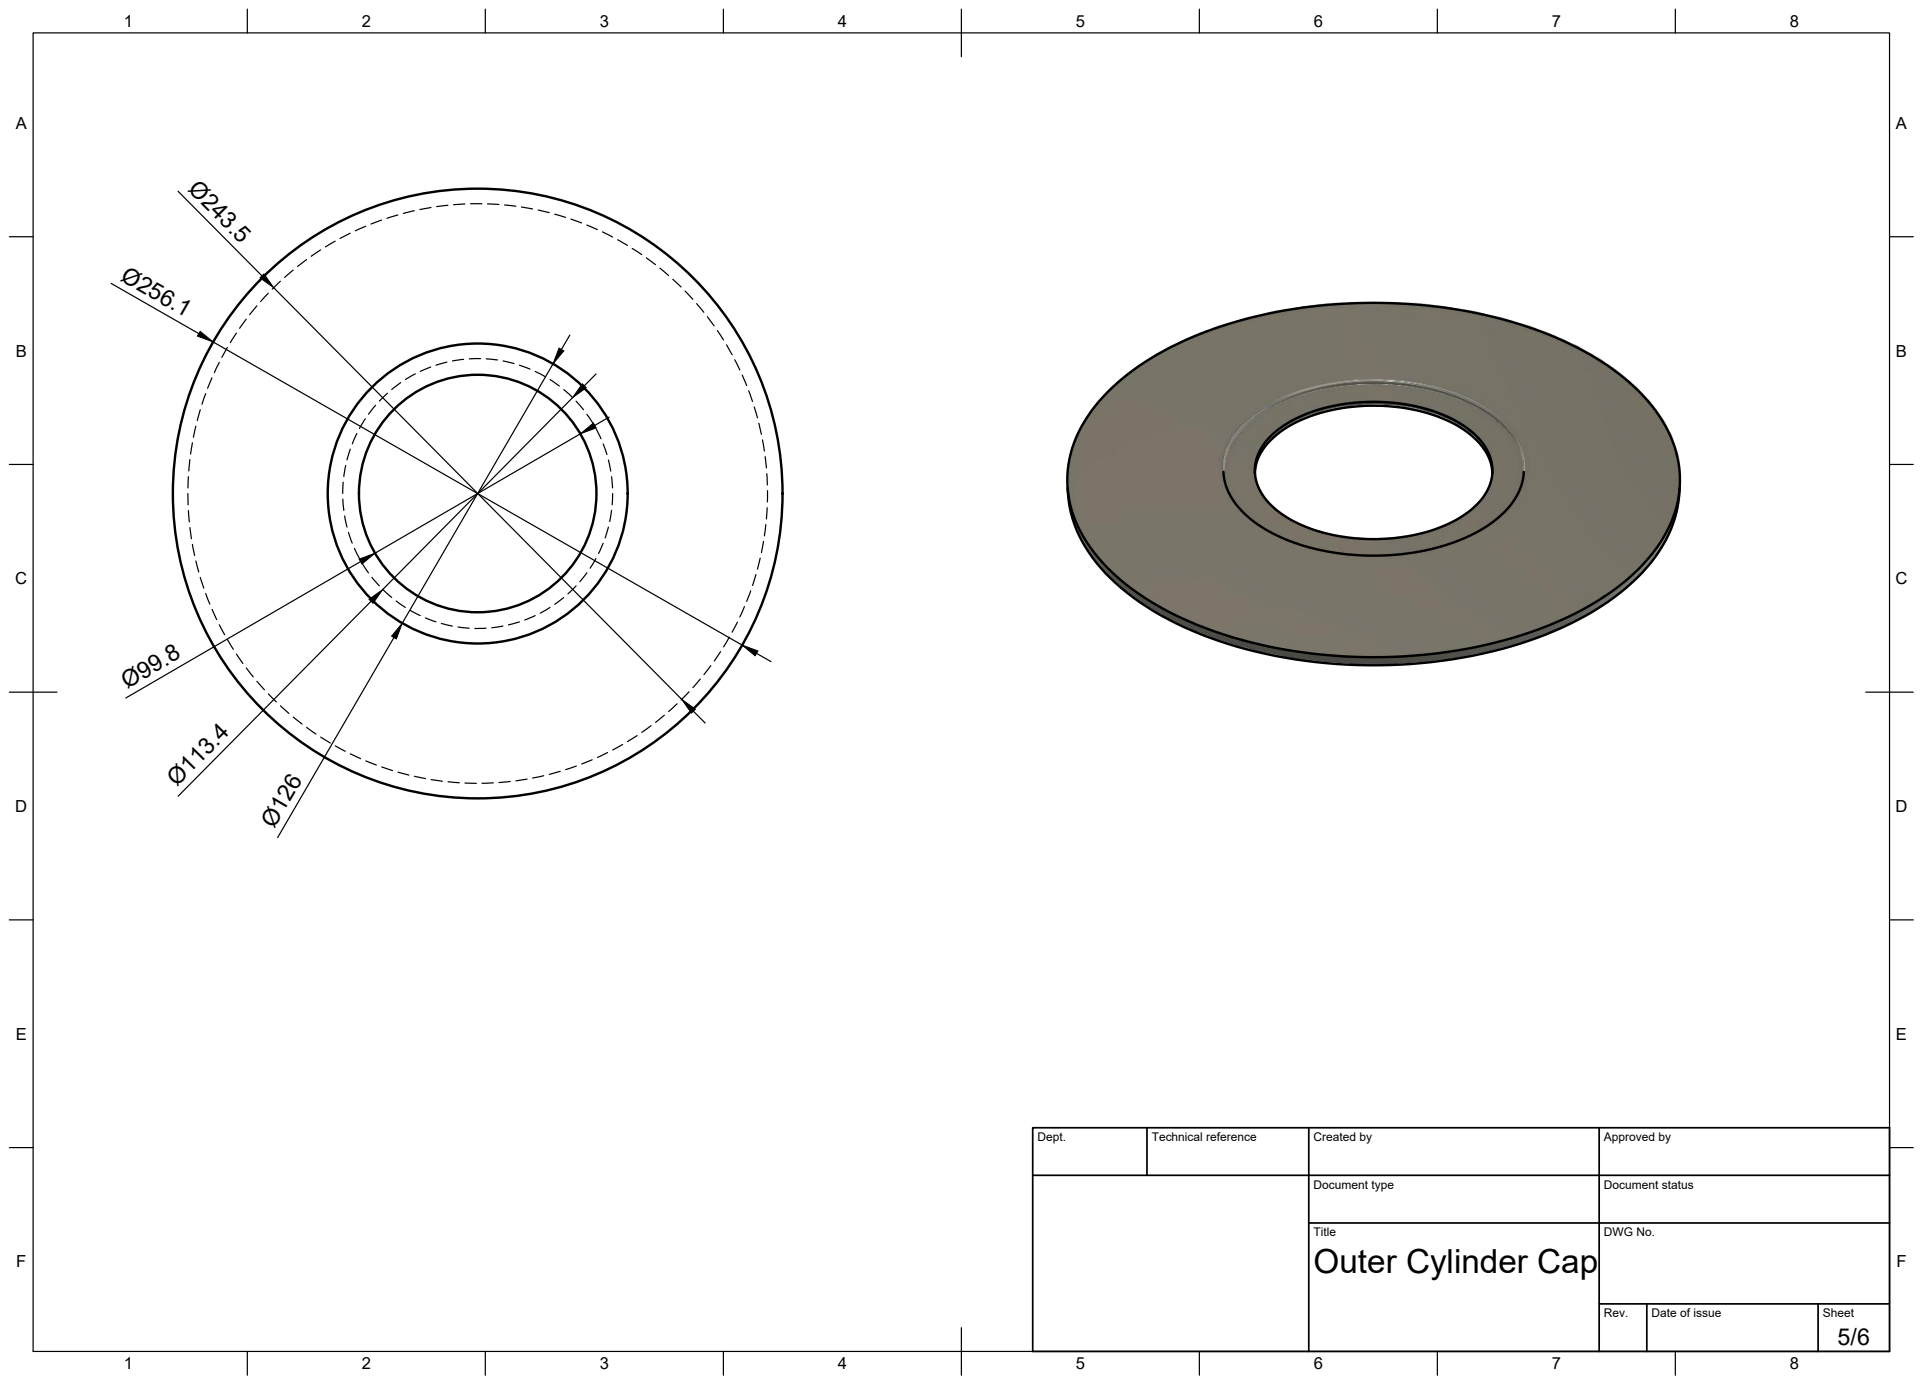
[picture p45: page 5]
Title; DWG No.

Dept. | Technical reference | Created by | Approved by

Document type | Document status

Outer Cylinder Cap

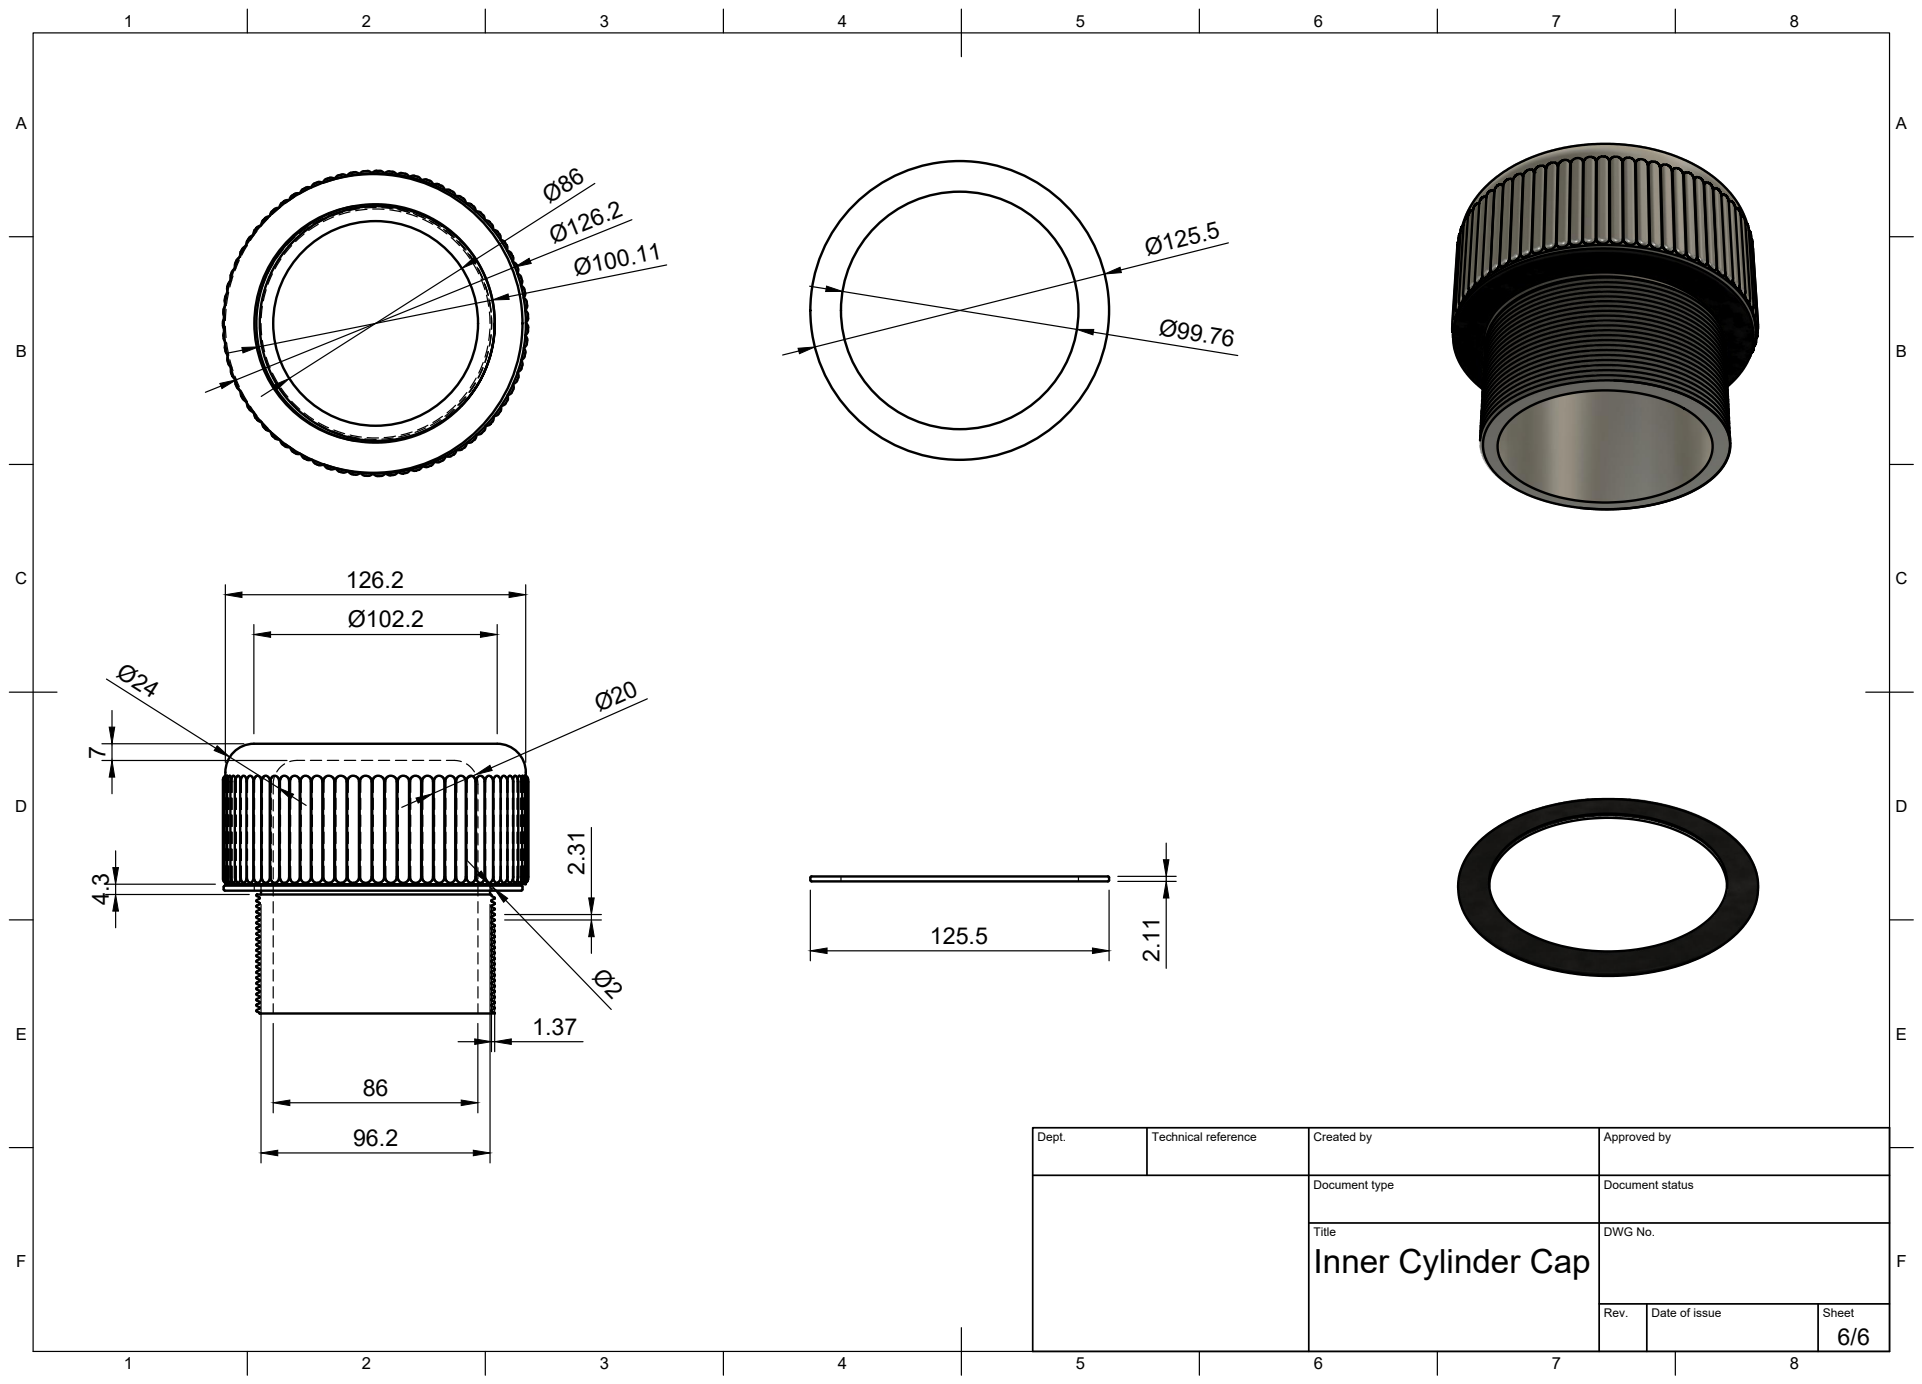
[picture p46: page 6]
Title; DWG No.

Inner Cylinder Cap 2.31

Dept. | Technical reference | Created by | Approved by

Document type | Document status
